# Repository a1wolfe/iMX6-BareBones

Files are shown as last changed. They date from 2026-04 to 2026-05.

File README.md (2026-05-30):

# iMX6 Bare Bones

An open source development board using the NXP i.MX 6ULL application processor. This design was completed using KiCad version 9.0.6.

See the Wiki page for updates on the status of this project.

## Related Repositories
Yocto project and images: https://github.com/a1wolfe/iMX6-BareBones-Yocto

Enclosure: https://github.com/a1wolfe/iMX6-BareBones-Enclosure

## Objectives

The iMX6 Bare Bones project was created with the following objectives:
- Create an open source PCBA for learning digital hardware and embedded linux design
- Implement minimum peripherals and interfaces to prioritize simplicity
- Specified impedance control using a standard PCB stackup published by a low-cost fabricator
- Power management using buck converters and LDOs, with no complex PMICs
- Expose interfaces such as GPIO, SPI, I2C and CAN over standard 0.1 inch / 2.54 mm headers. Users can create their own daughter PCBAs.
- Can be powered from a widely available power adapter (USB C, 15W selected)

## Architecture

System Block Diagram:

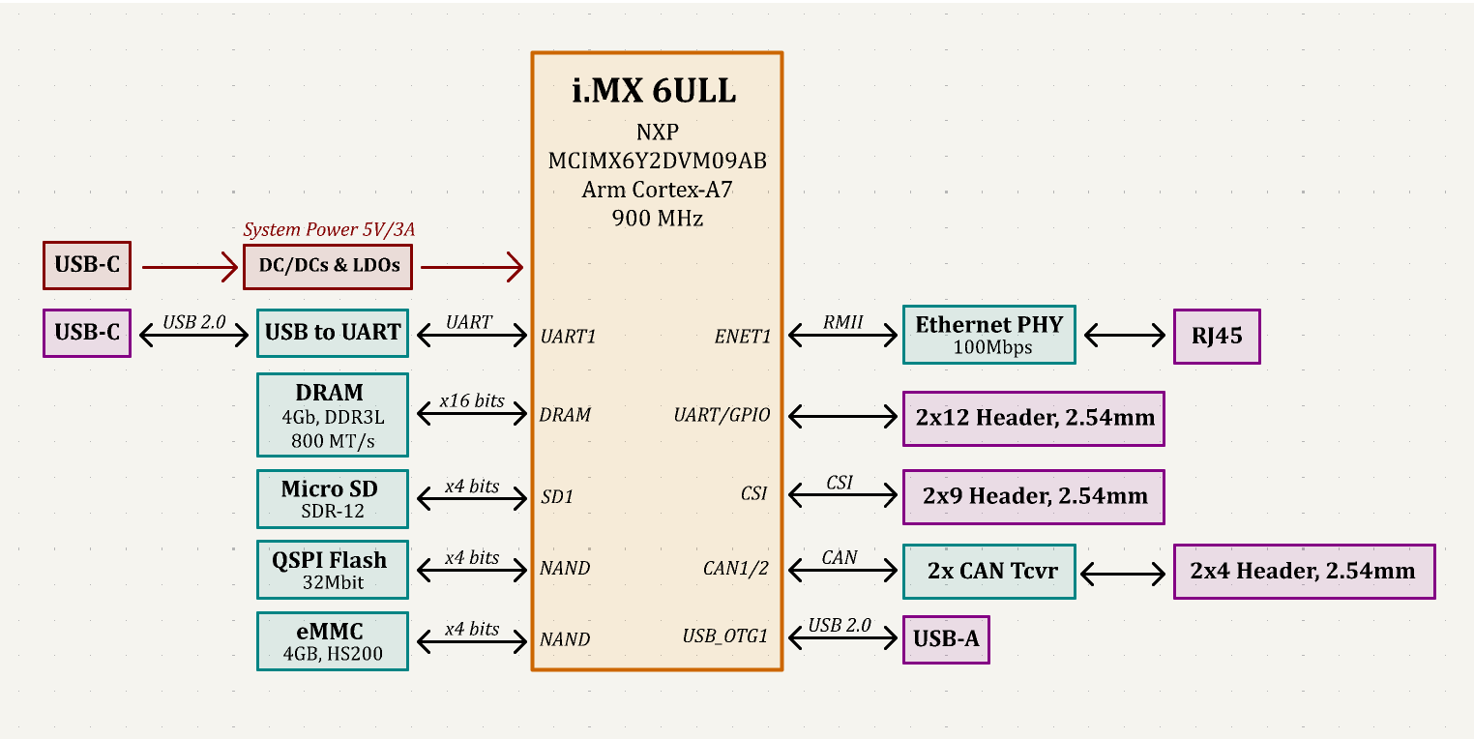
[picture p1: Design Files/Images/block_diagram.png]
block_diagram


<br>The i.MX 6ULL processor was selected mainly for it's simple and forgiving boot sequence requirements.

## PCB Design and Layout

PCBA, Top 3D View

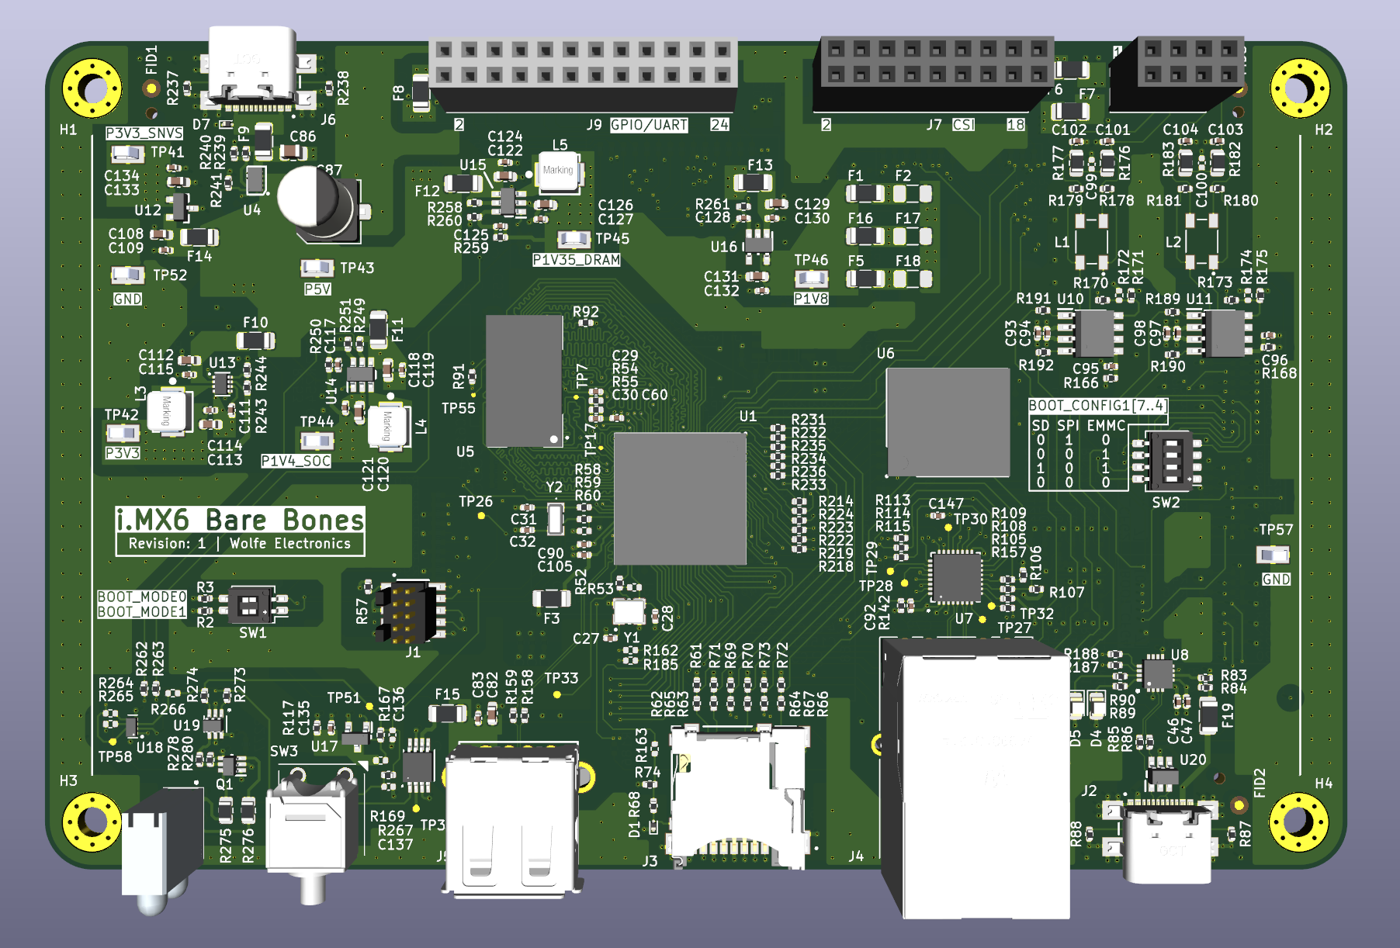
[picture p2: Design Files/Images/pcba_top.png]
pcba_top


<br>PCBA, Bottom 3D View

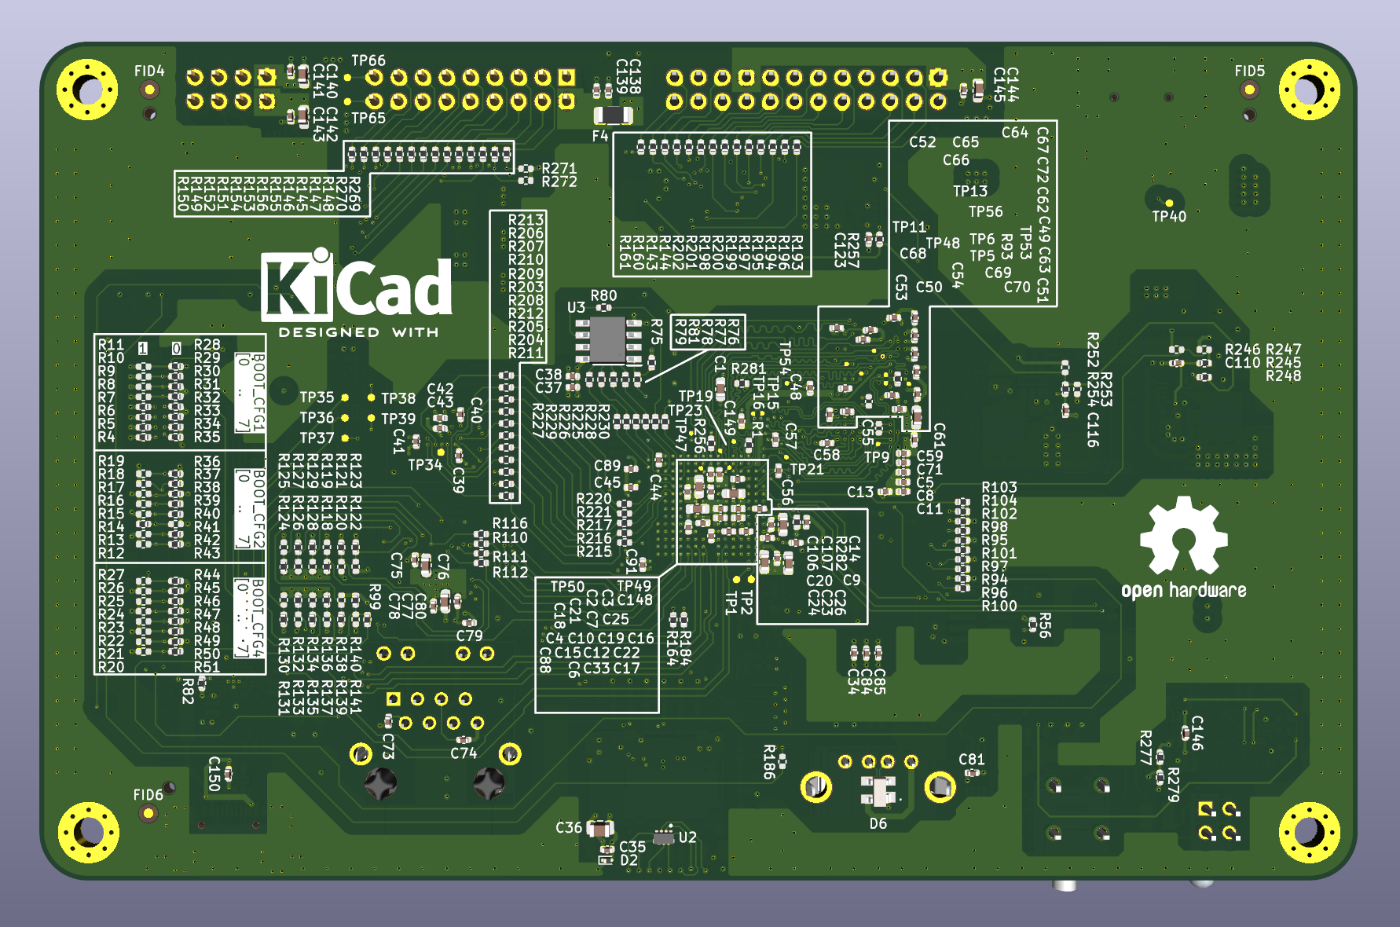
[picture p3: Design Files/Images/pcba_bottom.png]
pcba_bottom
<br>

### Placement
- All I/O connectors are placed along a single board edge. This enables easy cable insertion from the front of a system with an enclosure design.
- The power input is a USB C connector on the opposite board edge. A 15W wall adapter can be plugged into the back of a system.
- The 0.1 inch vertical headers allow daughter boards to be installed on top of the system. 
- Most components are placed on the top side of the PCB. The bottom was reserved mostly for passives and smaller SMD components. The largest component on the bottom is the QSPI flash U3, with a height of 63 mils / 1.6 mm.

### Stackup
- The PCB thickness was selected to be 1.6 mm. The design intent was to use a standard stackup listed online from a low-cost PCBA manufacturer.
- The selection was made while considering several factors to enable impedance control and DDR routing:
  - DDR3 requires 50 ohm impedance for single ended, and 100 ohm impedance for differential signals
  - Routing a x16 DDR interface while maintaining sufficient clearance between traces requires relatively thin traces. The i.MX 6ULL HDG recommends a trace width of 4.5 mils, which is used on their SODIMM reference design.
  - The thinnest outer-layer prepreg I coud find in a 1.6 mm stackup was JLC061611_3313D from JLCPCB. The prepreg thickness is 3.62 mils / 0.092 mm in this stackup.
  - Using JLC PCB's online [impdedance calculator](https://jlcpcb.com/impedance), this requires a trace width of 5.62 mm for 50 ohm single ended signals.

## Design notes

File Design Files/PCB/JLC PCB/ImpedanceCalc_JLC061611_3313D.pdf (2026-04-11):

# JLCPCB Impedance Calculator

The JLCPCB Impedance Calculator computes track width values and recommended stack-ups from user-input values of board layer, thickness, copper weight, target impedance, trace spacing (for edge-coupled pairs), and impedance trace to copper gap (coplanar waveguides). Click here (https://jlcpcb.com/help/article/User-Guide-to-the-JLCPCB-Impedance-Calculator) to see the user guide of our impedance calculator.

* The first stack-up calculated below is highly recommended as it has lowest cost and quickest turn-around.

## Impedance Configure

New Impedance | Duplicate Impedance | Calculate
24-hour PCB production. Fast Delivery to United States. | Coupons (https://jlcpcb.com/coupon-center) | APP Download (https://jlcpcb.com/download) | USD
Layers | 6 |
PCB Thickness | 1.6 |
Inner Copper Weight | 1oz |
Outer Copper Weight | 1oz |
Unit | mil |
Impedance (Ω) | Type | Signal Layer | Top Ref | Bottom Ref

Trace Spacing
（mil）

Impedance trace to
copper（mil）
(https://jlcpcb.com/) | (https://cart.jlcpcb.com/shopcart/cart) | Order Now (https://cart.jlcpcb.com/quote?spm=jlcpcb.Public.2006) | My Account

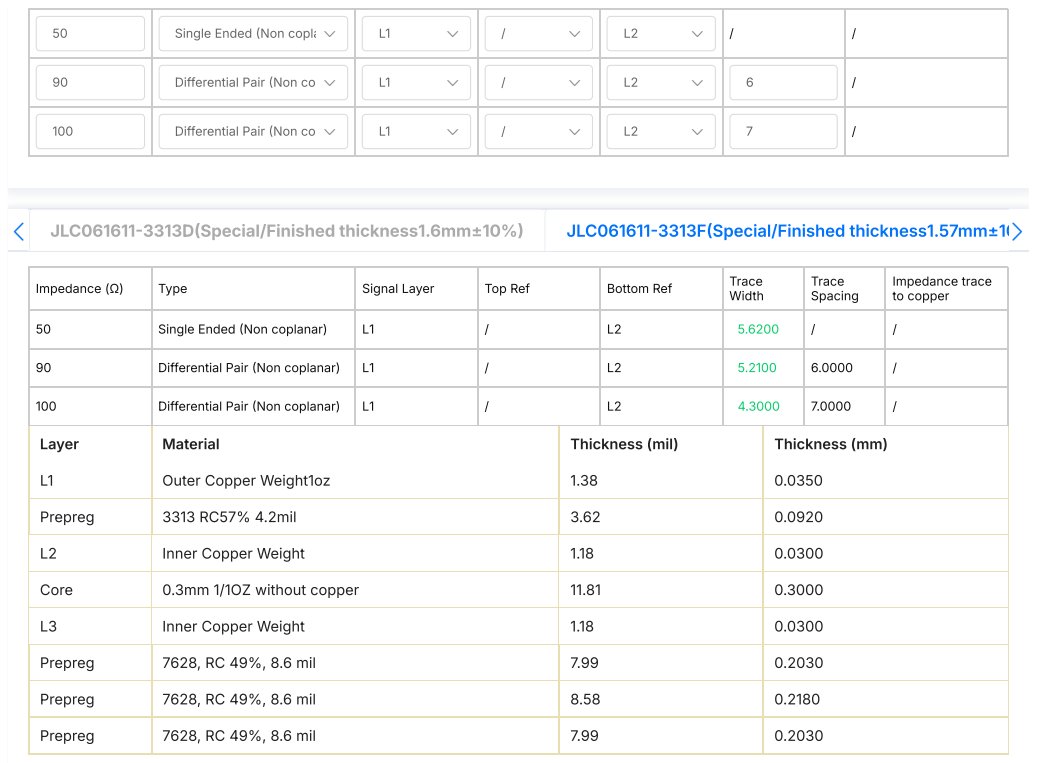
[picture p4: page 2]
JLC061611-3313D(Special/Finished thickness1.6mm±10%); JLC061611-3313F(Special/Finished thickness1.57mm±10

50 | Single Ended (Non copla | L1 | / | L2 | / | /

90 | Differential Pair (Non co | L1 | / | L2 | 6 | /

100 | Differential Pair (Non co | L1 | / | L2 | 7 | /

Impedance (Ω) | Type | Signal Layer | Top Ref | Bottom Ref | Trace Width | Trace Spacing | Impedance trace to copper

50 | Single Ended (Non coplanar) | L1 | / | L2 | 5.6200 | / | /

90 | Differential Pair (Non coplanar) | L1 | / | L2 | 5.2100 | 6.0000 | /

100 | Differential Pair (Non coplanar) | L1 | / | L2 | 4.3000 | 7.0000 | /

Layer | Material | Thickness (mil) | Thickness (mm)

L1 | Outer Copper Weight1oz | 1.38 | 0.0350

Prepreg | 3313 RC57% 4.2mil | 3.62 | 0.0920

L2 | Inner Copper Weight | 1.18 | 0.0300

Core | 0.3mm 1/1OZ without copper | 11.81 | 0.3000

L3 | Inner Copper Weight | 1.18 | 0.0300

Prepreg | 7628, RC 49%, 8.6 mil | 7.99 | 0.2030

Prepreg | 7628, RC 49%, 8.6 mil | 8.58 | 0.2180

© 2026 JLCPCB.COM All Rights Reserved. | Privacy Policy (https://jlcpcb.com/help/article/Privacy-Policy) | Terms & Conditions (https://jlcpcb.com/help/article/Terms-%26-Conditions) | Cookies Policy (https://jlcpcb.com/help/article/JLCPCB-Cookie-Notice)

L4

Core | 0.3mm 1/1OZ without copper | 11.81 | 0.3000
L5 | Inner Copper Weight | 1.18 | 0.0300
Prepreg | 3313 RC57% 4.2mil | 3.62 | 0.0920
L6 | Outer Copper Weight1oz | 1.38 | 0.0350

Inner Copper Weight
1.18

0.0300

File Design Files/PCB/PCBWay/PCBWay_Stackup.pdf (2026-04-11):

Thickness: 1.6MM | Finished Outer Copper: 1OZ | Inner Copper: 1OZ | Inner layer Residual copper ratio: 70%
Layer | Material | Thickness
| | | (mm) Thickness after lamination(mm)
| | L1-CU | Outer Base Copper
0.5OZ | 0.0175 | 0.0175
| | | (Plating to 1OZ)
| | PP | 2116 RC58%
DK:4.45 | 0.1300 | 0.1195
L2-CU | Inner Copper 1OZ | 0.0350
| | | 0.5
(Core with Cu) CORE | Core
DK:4.6 | 0.4300
L3-CU | Inner Copper 1OZ | 0.0350
PP | 7628 RC46%
DK:4.74 | 0.1960 | 0.1750
L4-CU | Inner Copper 1OZ | 0.0350

0.5

(Core with Cu) CORE | Core
DK:4.6 | 0.4300
L5-CU | Inner Copper 1OZ | 0.0350
PP | 2116 RC58%
DK:4.45 | 0.1300 | 0.1195
L6-CU | Outer Base Copper
0.5OZ | 0.0175 | 0.0175
(Plating to 1OZ)

L2-CU

L4-CU

L1-CU

PP

## CORE

L3-CU

PP

## CORE

L5-CU

PP

L6-CU

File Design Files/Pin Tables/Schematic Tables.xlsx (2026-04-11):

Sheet: BOOT_MODE
BOOT_MODE[1:0] | Boot Type
00 | Boot from fuses
01 | Serial downloader
10 | Internal boot
11 | Reserved

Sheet: BOOT_CFG
Boot Device | BOOT_CFG1[7] | BOOT_CFG1[6] | BOOT_CFG1[5] | BOOT_CFG1[4] | BOOT_CFG1[3] | BOOT_CFG1[2] | BOOT_CFG1[1] | BOOT_CFG1[0]
SD/eSD | 0 | 1 | 0 | Fast boot 0: Regular 1: Fast Boot | SD/SDXC speed 00: Normal/SDR12 01: High/SDR25 10: SDR50 11: SDR104 |  | SD power cycle enable 0: No 1: Enabled | SD loopback clock source 0: Through SD pad 1: Direct
QSPI | 0 | 0 | 0 | 1 | 0: QSPI0 | DDRSMP 000: Default 001: 111
MMC/eMMC | 0 | 1 | 1 | Fast boot 0: Regular 1: Fast Boot | SD/MMC Speed 0: Normal 1: High | Fast boot acknowledge 0: Boot ack enabled 1: Boot ack disabled | SD power cycle enable 0: No 1: Enabled | SD loopback clock source 0: Through SD pad 1: Direct
Default (SD) | 0 (SW2) | 1 (SW2) | 0 (SW2) | 0 (SW2) | 0 | 0 | 0 | 0
Boot Device | BOOT_CFG2[7] | BOOT_CFG2[6] | BOOT_CFG2[5] | BOOT_CFG2[4] | BOOT_CFG2[3] | BOOT_CFG2[2] | BOOT_CFG2[1] | BOOT_CFG2[0]
SD/eSD | SD Calibration Step 00: 1 delay cell |  | Bus Width 0: 1-bit 1: 4-bit | Port Select 00: eSDHC1 01: eSDHC2 10: Reserved 11: Reserved |  | Boot Frequencies (ARM/DDR) 0: 500 / 400 MHz 1: 250 / 200 MHz | SD VOLTAGE SELECTION 0: 3.3V 1: 1.8V | Reserved
QSPI | Reserved | HSPHS (Half Speed Phase Selection) 0: select sampling at non-inverted clock 1: select sampling at inverted clock | HSDLY (Half Speed Delay selection) 0: one clock delay 1: two clock delay | FSPHS (Full Speed Phase Selection) 0: select sampling at non-inverted clock 1: select sampling at inverted clock | FSDLY (Full Speed Delay selection) 0: one clock delay 1: two clock delay | Boot Frequencies (ARM/DDR) 0: 500 / 400 MHz 1: 250 / 200 MHz | Reserved | Reserved
MMC/eMMC | Bus Width 000: 1-bit 001: 4-bit 010: 8-bit 101: 4-bit DDR (MMC 4.4) 110: 8-bit DDR (MMC 4.4) Else: Reserved |  |  | Port Select 00: eSDHC1 01: eSDHC2 10: Reserved 11: Reserved |  | Boot Frequencies (ARM/DDR) 0: 500 / 400 MHz 1: 250 / 200 MHz | SD VOLTAGE SELECTION 0: 3.3V 1: 1.8V | Reserved
Default (SD) | 0 | 0 | 1 | 0 | 0 | 0 | 0 | 0
Boot Device | BOOT_CFG4[7] | BOOT_CFG4[6] | BOOT_CFG4[5] | BOOT_CFG4[4] | BOOT_CFG4[3] | BOOT_CFG4[2] | BOOT_CFG4[1] | BOOT_CFG4[0]
SD/eSD MMC/eMMC | Reserved | EEPROM Recovery Enable 0: Disabled 1: Enabled Fuse is Reserved for 'Serial-ROM' Boot mode | eCSPI chip select 00: ECSPIx_SS0 (default) 01: ECSPIx_SS1 10: ECSPIx_SS2 11: ECSPIx_SS3 |  | eCSPI Addressing 0: 2-bytes (16-bit) 1: 3-bytes (24-bit) | Port Select 000: eCSPI1 001: eCSPI2 010: eCSPI3 011: eCSPI4 100 to 111: Reserved
Default (SD) | 0 | 0 | 0 | 0 | 0 | 0 | 0 | 0

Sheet: RMII
Pin Name | Description | Pin Name | Description
PHY_ADDRESS[2:0] | PHY Address (00XXX) Default: 00001 | CONFIG[2:0] | Interface Mode Default: 001 (RMII)
 |  |  |  | Pin Name | Description
 |  |  |  | ISO | Isolate Mode Pull-up: Enable Pull-down (default): Disable
 |  |  |  | SPEED | Speed mode Pull-up (default) = 100 Mbps Pull-down = 10 Mbps
 |  |  |  | DUPLEX | Duplex mode Pull-up (default) = Half-duplex Pull-down = Full-duplex
 |  |  |  | NWAYEN | Nway auto-negotiation enable Pull-up (default) = Enable auto-negotiation Pull-down = Disable auto-negotiation
 |  |  |  | B-CAST_OFF | Broadcast off – for PHY Address 0 Pull-up = PHY Address 0 is set as an unique PHY address Pull-down (default) = PHY Address 0 is set as a broadcast PHY address
 |  |  |  | NAND_Tree# | NAND tree mode Pull-up (default) = Disable Pull-down = Enable

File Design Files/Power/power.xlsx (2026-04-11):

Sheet: Power Budget
Device | Pins | Voltage | Rail | Continuous Max (mA) | N (IO pins) | C (cap load, pF) | Freq (Hz) | Sequence
iMX6 | VDD_SOC_IN | 1.4 | P1V4_SOC | 500 | N/A | N/A | N/A | 3
iMX6 | VDD_HIGH_IN | 3.3 | P3V3 | 125 | N/A | N/A | N/A | 2
iMX6 | VDD_SNVS_IN | 3.3 | P3V3_STBY | 0.5 | N/A | N/A | N/A | 1
iMX6 | NVCC_DRAM | 1.35 | P1V35_DRAM | 50 | N/A | N/A | N/A
iMX6 | VDDA_ADC_3P3 | 3.3 | P3V3 | 35 | N/A | N/A | N/A
iMX6 | USB_OTG1_VBUS | 5 | P5V | 50 | N/A | N/A | N/A
iMX6 | USB_OTG2_VBUS | 5 | P5V | 50 | N/A | N/A | N/A
iMX6 | NVCC_SD1 | 3.3 | P3V3 | 9.90 | 6 | 10 | 50000000
iMX6 | NVCC_NAND | 1.8 | P1V8 | 6.12 | 17 | 10 | 20000000
iMX6 | NVCC_CSI | 1.8 | P1V8 | 2.59 | 12 | 10 | 12000000
iMX6 | NVCC_LCD | 3.3 | P3V3 | 28.71 | 29 | 10 | 30000000
iMX6 | NVCC_ENET | 3.3 | P3V3 | 13.20 | 16 | 10 | 25000000
iMX6 | NVCC_UART | 3.3 | P3V3 | 0.06 | 16 | 10 | 115200
iMX6 | NVCC_GPIO | 3.3 | P3V3 | 0.0033 | 10 | 10 | 10000
iMX6 | DRAM_VREF | 1.35 | P1V35_DRAM | 1 | N/A | N/A | N/A
MT41K256M16TW-107 | VDD/VDDQ | 1.35 | P1V35_DRAM | 320
CP2102N | VREGIN/VDD | 3.3 | P3V3 | 9.5
eMMC | VCCQ | 1.8 | P1V8 | 185
uSD | VDD | 3.3 | P3V3 | 300
QSPI Flash | VCC | 3.3 | P3V3 | 17
KSZ8081 phy | VDDA/VDDIO | 3.3 | P3V3 | 47
CAN transceiver (x2) | VCC | 5 | P5V | 140
CAN transceiver (x2) | VIO | 3.3 | P3V3 | 0.7

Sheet: P5V OVLO
 | min | typical | max
Vth(ovlo) | 1.164 | 1.227 | 1.287 | Vovlo desired | 8 | From NX20P5090 datasheet:
R1 | 990000 | 1000000 | 1010000 | R2 calculated | 181160.4902
R2 | 180180 | 182000 | 183820 | R2 actual | 182000
Vovlo | 7.559604396 | 7.968758242 | 8.358428571

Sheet: P3V3
From MPS2182 Datasheet:
 |  |  | Vout | 3.3
 |  |  | Vin | 5
 |  |  | Max I (A) | 0.78
 |  |  | delta I | 0.234
 |  |  | fosc | 1200000
 |  |  | L | 3.995726496e-06
 |  |  | Calculated value outside of recommended range, will select 1uH.
 |  |  |  |  | Vout | 3.3
 |  |  |  |  | Vin | 5
 |  |  |  |  | fsw | 1200000
 |  | Selected X7R, 10uF input cap |  |  | C2 | 2.2e-05
 |  |  |  |  | L1 | 1e-06
 |  |  |  |  | delta Vout | 0.004427083333
 |  |  |  |  | Select 22uF for output capacitor
For 3.3V, selected 200k and 44.2k
Vout | 3.3
R2 | 44444.44444
R1 | 200000
R2 select | 44200
Vout actual | 3.314932127

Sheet: P1V4_SOC & P1V35_DRAM
P1V4_SOC |  | P1V35_DRAM
R1 | 100000 | R1 | 100000
R2 | 75000 | R2 | 80000
Vout | 1.4 | Vout | 1.35

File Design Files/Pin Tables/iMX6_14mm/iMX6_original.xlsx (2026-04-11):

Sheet: iMX6_Original
Count | Pin | Net | Electrical | Shape | Alignment | Coordinate 1 | Coordinate 2 | Symbol
1 | A1 | VSS_1 | Passive | Line | Right | 0 mils | 0 mils | GND
1 | C4 | NVCC_SD1 | Passive | Line | Right | 0 | 400 | SD
1 | E7 | NVCC_NAND | Passive | Line | Right | 0 | 400 | NAND
1 | B4 | NAND_ALE | Passive | Line | Left | 2300 | 400 | NAND
1 | C8 | NAND_WE_B | Passive | Line | Left | 2300 | 500 | NAND
1 | D8 | NAND_RE_B | Passive | Line | Left | 2300 | 600 | NAND
1 | D7 | NAND_DATA00 | Passive | Line | Left | 2300 | 700 | NAND
1 | A8 | LCD_CLK | Passive | Line | Left | 2300 | 400 | LCD
1 | B9 | LCD_DATA00 | Passive | Line | Left | 2300 | 600 | LCD
1 | A9 | LCD_DATA01 | Passive | Line | Left | 2300 | 700 | LCD
1 | E10 | LCD_DATA02 | Passive | Line | Left | 2300 | 800 | LCD
1 | D10 | LCD_DATA03 | Passive | Line | Left | 2300 | 900 | LCD
1 | C10 | LCD_DATA04 | Passive | Line | Left | 2300 | 1000 | LCD
1 | B10 | LCD_DATA05 | Passive | Line | Left | 2300 | 1100 | LCD
1 | F16 | ENET1_RX_DATA0 | Passive | Line | Right | 0 mils | 600 | ENET
1 | E17 | ENET1_RX_DATA1 | Passive | Line | Right | 0 mils | 700 | ENET
1 | A17 | VSS_2 | Passive | Line | Right | 0 mils | 1600 mils | GND
1 | C1 | SD1_CLK | Passive | Line | Left | 2300 | 400 | SD
1 | C2 | SD1_CMD | Passive | Line | Left | 2300 | 500 | SD
1 | B3 | SD1_DATA0 | Passive | Line | Left | 2300 | 700 | SD
1 | B7 | NAND_DATA01 | Passive | Line | Left | 2300 | 800 | NAND
1 | A7 | NAND_DATA02 | Passive | Line | Left | 2300 | 900 | NAND
1 | D6 | NAND_DATA03 | Passive | Line | Left | 2300 | 1000 | NAND
1 | C6 | NAND_DATA04 | Passive | Line | Left | 2300 | 1100 | NAND
1 | A10 | LCD_DATA06 | Passive | Line | Left | 2300 | 1200 | LCD
1 | D11 | LCD_DATA07 | Passive | Line | Left | 2300 | 1300 | LCD
1 | B11 | LCD_DATA08 | Passive | Line | Left | 2300 | 1400 | LCD
1 | A11 | LCD_DATA09 | Passive | Line | Left | 2300 | 1500 | LCD
1 | E12 | LCD_DATA10 | Passive | Line | Left | 2300 | 1600 | LCD
1 | D12 | LCD_DATA11 | Passive | Line | Left | 2300 | 1700 | LCD
1 | C12 | LCD_DATA12 | Passive | Line | Left | 2300 | 1800 | LCD
1 | E16 | ENET1_RX_EN | Passive | Line | Right | 0 mils | 900 | ENET
1 | B12 | LCD_DATA13 | Passive | Line | Left | 2300 | 1900 | LCD
1 | D15 | ENET1_RX_ER | Passive | Line | Right | 0 mils | 1000 | ENET
1 | B2 | SD1_DATA1 | Passive | Line | Left | 2300 | 800 | SD
1 | B1 | SD1_DATA2 | Passive | Line | Left | 2300 | 900 | SD
1 | C3 | VSS_3 | Passive | Line | Right | 0 mils | 3600 mils | GND
1 | A2 | SD1_DATA3 | Passive | Line | Left | 2300 | 1000 | SD
1 | B6 | NAND_DATA05 | Passive | Line | Left | 2300 | 1200 | NAND
1 | A6 | NAND_DATA06 | Passive | Line | Left | 2300 | 1300 | NAND
1 | C7 | VSS_4 | Passive | Line | Right | 0 mils | 4000 mils | GND
1 | A5 | NAND_DATA07 | Passive | Line | Left | 2300 | 1400 | NAND
1 | A12 | LCD_DATA14 | Passive | Line | Left | 2300 | 2000 | LCD
1 | D13 | LCD_DATA15 | Passive | Line | Left | 2300 | 2100 | LCD
1 | C11 | VSS_5 | Passive | Line | Right | 0 mils | 4400 mils | GND
1 | C13 | LCD_DATA16 | Passive | Line | Left | 2300 | 2200 | LCD
1 | B13 | LCD_DATA17 | Passive | Line | Left | 2300 | 2300 | LCD
1 | A13 | LCD_DATA18 | Passive | Line | Left | 2300 | 2400 | LCD
1 | C15 | VSS_6 | Passive | Line | Right | 0 mils | 4800 mils | GND
1 | F14 | ENET1_TX_CLK | Passive | Line | Left | 2300 | 400 | ENET
1 | E15 | ENET1_TX_DATA0 | Passive | Line | Left | 2300 | 600 | ENET
1 | F4 | NVCC_CSI | Passive | Line | Right | 0 | 700 | CSI
1 | F5 | CSI_MCLK | Passive | Line | Left | 2300 | 900 | CSI
1 | E5 | CSI_PIXCLK | Passive | Line | Left | 2300 | 1000 | CSI
1 | F2 | CSI_VSYNC | Passive | Line | Left | 2300 | 600 | CSI
1 | C5 | NAND_CE0_B | Passive | Line | Left | 2300 | 1600 | NAND
1 | B5 | NAND_CE1_B | Passive | Line | Left | 2300 | 1700 | NAND
1 | A4 | NAND_CLE | Passive | Line | Left | 2300 | 1800 | NAND
1 | D5 | NAND_WP_B | Passive | Line | Left | 2300 | 1900 | NAND
1 | D14 | LCD_DATA19 | Passive | Line | Left | 2300 | 2500 | LCD
1 | C14 | LCD_DATA20 | Passive | Line | Left | 2300 | 2600 | LCD
1 | B14 | LCD_DATA21 | Passive | Line | Left | 2300 | 2700 | LCD
1 | A14 | LCD_DATA22 | Passive | Line | Left | 2300 | 2800 | LCD
1 | B16 | LCD_DATA23 | Passive | Line | Left | 2300 | 2900 | LCD
1 | B8 | LCD_ENABLE | Passive | Line | Left | 2300 | 3100 | LCD
1 | E14 | ENET1_TX_DATA1 | Passive | Line | Left | 2300 | 700 | ENET
1 | F15 | ENET1_TX_EN | Passive | Line | Left | 2300 | 900 | ENET
1 | C17 | ENET2_RX_DATA0 | Passive | Line | Right | 0 mils | 1200 | ENET
1 | F3 | CSI_HSYNC | Passive | Line | Left | 2300 | 700 | CSI
1 | E4 | CSI_DATA00 | Passive | Line | Left | 2300 | 800 | CSI
1 | E3 | CSI_DATA01 | Passive | Line | Left | 2300 | 900 | CSI
1 | E2 | CSI_DATA02 | Passive | Line | Left | 2300 | 1000 | CSI
1 | E1 | CSI_DATA03 | Passive | Line | Left | 2300 | 1100 | CSI
1 | A3 | NAND_READY_B | Passive | Line | Left | 2300 | 2000 | NAND
1 | E6 | NAND_DQS | Passive | Line | Left | 2300 | 2100 | NAND
1 | E8 | VSS_7 | Passive | Line | Right | 0 mils | 7500 mils | GND
1 | D9 | LCD_HSYNC | Passive | Line | Left | 2300 | 3200 | LCD
1 | E9 | LCD_RESET | Passive | Line | Left | 2300 | 3300 | LCD
1 | E11 | VSS_8 | Passive | Line | Right | 0 mils | 7800 mils | GND
1 | C9 | LCD_VSYNC | Passive | Line | Left | 2300 | 3400 | LCD
1 | E13 | NVCC_LCD | Passive | Line | Right | 0 | 400 | LCD
1 | C16 | ENET2_RX_DATA1 | Passive | Line | Right | 0 mils | 1300 | ENET
1 | B17 | ENET2_RX_EN | Passive | Line | Right | 0 mils | 1500 | ENET
1 | D16 | ENET2_RX_ER | Passive | Line | Right | 0 mils | 1600 | ENET
1 | D17 | ENET2_TX_CLK | Passive | Line | Left | 2300 | 1100 | ENET
1 | N1 | DRAM_ODT0 | Passive | Line | Left | 2300 mils | 3100 | DRAM | B
1 | D4 | CSI_DATA04 | Passive | Line | Left | 2300 | 1200 | CSI
1 | D3 | CSI_DATA05 | Passive | Line | Left | 2300 | 1300 | CSI
1 | D2 | CSI_DATA06 | Passive | Line | Left | 2300 | 1400 | CSI
1 | D1 | CSI_DATA07 | Passive | Line | Left | 2300 | 1500 | CSI
1 | F6 | VSS_9 | Passive | Line | Right | 0 mils | 9000 mils | GND
1 | F7 | VSS_10 | Passive | Line | Right | 0 mils | 9100 mils | GND
1 | F8 | VSS_11 | Passive | Line | Right | 0 mils | 9200 mils | GND
1 | F9 | VSS_12 | Passive | Line | Right | 0 mils | 9300 mils | GND
1 | F10 | VSS_13 | Passive | Line | Right | 0 mils | 9400 mils | GND
1 | F11 | VSS_14 | Passive | Line | Right | 0 mils | 9500 mils | GND
1 | F12 | VSS_15 | Passive | Line | Right | 0 mils | 9600 mils | GND
1 | A15 | ENET2_TX_DATA0 | Passive | Line | Left | 2300 | 1200 | ENET
1 | A16 | ENET2_TX_DATA1 | Passive | Line | Left | 2300 | 1400 | ENET
1 | B15 | ENET2_TX_EN | Passive | Line | Left | 2300 | 1500 | ENET
1 | F13 | NVCC_ENET | Passive | Line | Right | 0 mils | 300 | ENET
1 | M13 | ADC_VREFH | Passive | Line | Left | 2300 mils | 5400 mils | PMU
1 | L5 | DRAM_ADDR00 | Passive | Line | Right | 0 mils | 0 mils | DRAM | B
1 | H2 | DRAM_ADDR01 | Passive | Line | Right | 0 mils | 100 mils | DRAM | B
1 | G3 | VSS_16 | Passive | Line | Right | 0 mils | 10400 mils | GND
1 | G4 | DRAM_RESET | Passive | Line | Right | 0 mils | 3400 | DRAM | B
1 | G5 | VSS_17 | Passive | Line | Right | 0 mils | 10600 mils | GND
1 | G6 | NVCC_DRAM_1 | Passive | Line | Right | 0 mils | 700 mils | PMU
1 | G7 | VSS_18 | Passive | Line | Right | 0 mils | 10800 mils | GND
1 | G8 | VDD_SOC_CAP_1 | Passive | Line | Left | 2100 mils | 700 mils | PMU
1 | G9 | VDD_ARM_CAP_1 | Passive | Line | Left | 2100 mils | 0 mils | PMU
1 | G10 | VDD_ARM_CAP_2 | Passive | Line | Left | 2100 mils | 100 mils | PMU
1 | G11 | VDD_ARM_CAP_3 | Passive | Line | Left | 2100 mils | 200 mils | PMU
1 | G12 | VSS_19 | Passive | Line | Right | 0 mils | 11300 mils | GND
1 | T10 | BOOT_MODE0 | Passive | Line | Left | 2300 mils | 300 | CTRL
1 | U10 | BOOT_MODE1 | Passive | Line | Left | 2300 mils | 400 | CTRL
1 | G15 | VSS_20 | Passive | Line | Right | 0 mils | 11600 mils | GND
1 | P16 | CCM_CLK1_N | Passive | Line | Left | 2300 mils | 500 | CTRL
1 | P17 | CCM_CLK1_P | Passive | Line | Left | 2300 mils | 600 | CTRL
1 | M1 | DRAM_SDBA0 | Passive | Line | Right | 0 mils | 1200 mils | DRAM | B
1 | K1 | DRAM_ADDR02 | Passive | Line | Right | 0 mils | 200 mils | DRAM | B
1 | M2 | DRAM_ADDR03 | Passive | Line | Right | 0 mils | 300 mils | DRAM | B
1 | K4 | DRAM_ADDR04 | Passive | Line | Right | 0 mils | 400 mils | DRAM | B
1 | N2 | DRAM_CS0_B | Passive | Line | Right | 0 | 2100 | DRAM | B
1 | H6 | NVCC_DRAM_2 | Passive | Line | Right | 0 mils | 800 mils | PMU
1 | H7 | VSS_21 | Passive | Line | Right | 0 mils | 12500 mils | GND
1 | H8 | VDD_SOC_CAP_2 | Passive | Line | Left | 2100 mils | 800 mils | PMU
1 | H9 | VDD_SOC_IN_1 | Passive | Line | Right | 0 mils | 0 mils | PMU
1 | H10 | VDD_SOC_IN_2 | Passive | Line | Right | 0 mils | 100 mils | PMU
1 | H11 | VDD_ARM_CAP_4 | Passive | Line | Left | 2100 mils | 300 mils | PMU
1 | H12 | VSS_22 | Passive | Line | Right | 0 mils | 13000 mils | GND
1 | U9 | CCM_PMIC_STBY_REQ | Passive | Line | Left | 2300 mils | 700 | CTRL
1 | R13 | GPANAIO | Passive | Line | Left | 2300 mils | 800 | CTRL
1 | P15 | JTAG_MOD | Passive | Line | Left | 2300 mils | 900 | CTRL
1 | M14 | JTAG_TCK | Passive | Line | Left | 2300 mils | 1000 | CTRL
1 | N16 | JTAG_TDI | Passive | Line | Left | 2300 mils | 1100 | CTRL
1 | J1 | DRAM_SDWE_B | Passive | Line | Right | 0 mils | 2600 | DRAM | B
1 | J2 | DRAM_CAS_B | Passive | Line | Right | 0 mils | 2500 | DRAM | B
1 | M3 | DRAM_SDCKE0 | Passive | Line | Left | 2300 mils | 2500 | DRAM | B
1 | L1 | DRAM_ADDR05 | Passive | Line | Right | 0 mils | 500 mils | DRAM | B
1 | J5 | VSS_23 | Passive | Line | Right | 0 mils | 14000 mils | GND
1 | J6 | NVCC_DRAM_3 | Passive | Line | Right | 0 mils | 900 mils | PMU
1 | J7 | VSS_24 | Passive | Line | Right | 0 mils | 14200 mils | GND
1 | J8 | VDD_SOC_CAP_3 | Passive | Line | Left | 2100 mils | 900 mils | PMU
1 | J9 | VDD_SOC_IN_3 | Passive | Line | Right | 0 mils | 200 mils | PMU
1 | J10 | VDD_SOC_IN_4 | Passive | Line | Right | 0 mils | 300 mils | PMU
1 | J11 | VDD_SOC_CAP_4 | Passive | Line | Left | 2100 mils | 1000 mils | PMU
1 | J12 | VSS_25 | Passive | Line | Left | 2300 mils | 200 mils | GND
1 | K13 | GPIO1_IO00 | Passive | Line | Left | 2300 mils | 300 | GPIO
1 | N15 | JTAG_TDO | Passive | Line | Left | 2300 mils | 1200 | CTRL
1 | P14 | JTAG_TMS | Passive | Line | Left | 2300 mils | 1300 | CTRL
1 | N14 | JTAG_TRST_B | Passive | Line | Left | 2300 mils | 1400 | CTRL
1 | M12 | NGND_KEL0 | Passive | Line | Left | 2300 mils | 3000 | GND
1 | G2 | DRAM_ADDR06 | Passive | Line | Right | 0 mils | 600 mils | DRAM | B
1 | H1 | DRAM_SDBA1 | Passive | Line | Right | 0 mils | 1300 mils | DRAM | B
1 | H4 | DRAM_ADDR07 | Passive | Line | Right | 0 mils | 700 mils | DRAM | B
1 | J4 | DRAM_ADDR08 | Passive | Line | Right | 0 mils | 800 mils | DRAM | B
1 | L2 | DRAM_ADDR09 | Passive | Line | Right | 0 mils | 900 mils | DRAM | B
1 | K6 | NVCC_DRAM_4 | Passive | Line | Right | 0 mils | 1000 mils | PMU
1 | K7 | VSS_26 | Passive | Line | Left | 2300 mils | 1400 mils | GND
1 | K8 | VDD_SOC_CAP_5 | Passive | Line | Left | 2100 mils | 1100 mils | PMU
1 | K9 | VDD_SOC_IN_5 | Passive | Line | Right | 0 mils | 400 mils | PMU
1 | K10 | VDD_SOC_IN_6 | Passive | Line | Right | 0 mils | 500 mils | PMU
1 | K11 | VDD_SOC_CAP_6 | Passive | Line | Left | 2100 mils | 1200 mils | PMU
1 | K12 | VSS_27 | Passive | Line | Left | 2300 mils | 1900 mils | GND
1 | L15 | GPIO1_IO01 | Passive | Line | Left | 2300 mils | 400 | GPIO
1 | H13 | NVCC_UART | Passive | Line | Right | 0 mils | 300 | UART
1 | R8 | ONOFF | Passive | Line | Left | 2300 mils | 1600 | CTRL
1 | P8 | POR_B | Passive | Line | Left | 2300 mils | 1700 | CTRL
1 | L14 | GPIO1_IO02 | Passive | Line | Left | 2300 mils | 500 | GPIO
1 | M4 | DRAM_ADDR10 | Passive | Line | Right | 0 mils | 1000 mils | DRAM | B
1 | K3 | DRAM_ADDR11 | Passive | Line | Right | 0 mils | 1100 mils | DRAM | B
1 | L3 | VSS_28 | Passive | Line | Left | 2300 mils | 2700 mils | GND
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

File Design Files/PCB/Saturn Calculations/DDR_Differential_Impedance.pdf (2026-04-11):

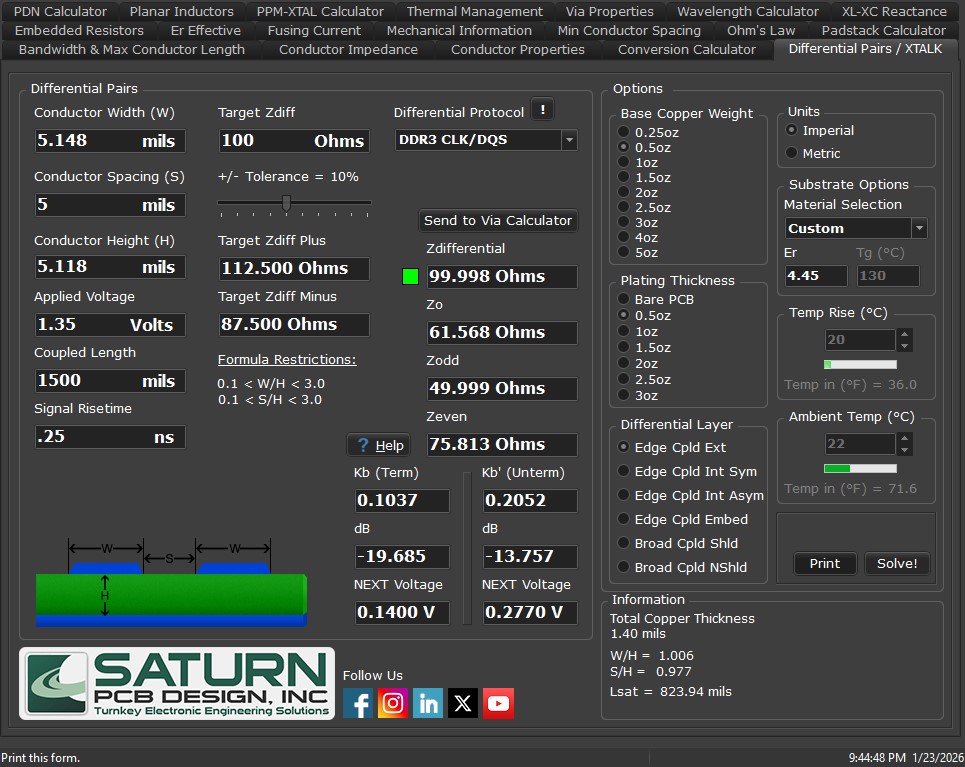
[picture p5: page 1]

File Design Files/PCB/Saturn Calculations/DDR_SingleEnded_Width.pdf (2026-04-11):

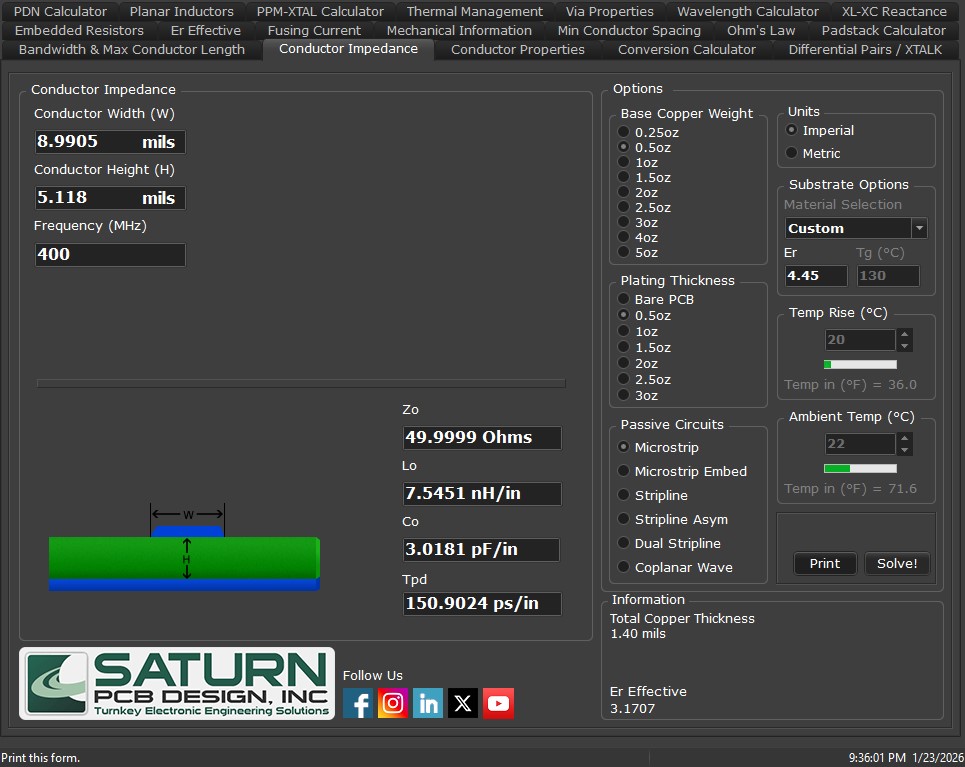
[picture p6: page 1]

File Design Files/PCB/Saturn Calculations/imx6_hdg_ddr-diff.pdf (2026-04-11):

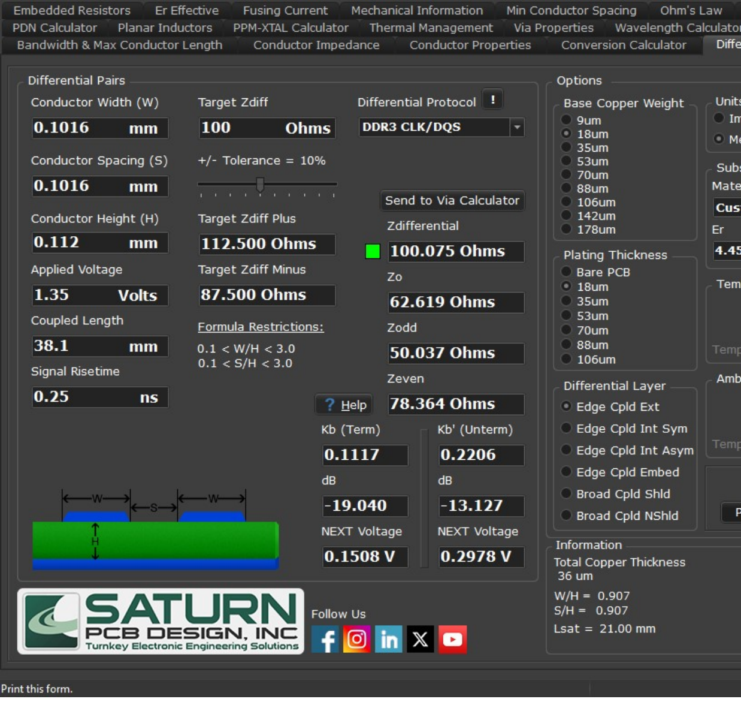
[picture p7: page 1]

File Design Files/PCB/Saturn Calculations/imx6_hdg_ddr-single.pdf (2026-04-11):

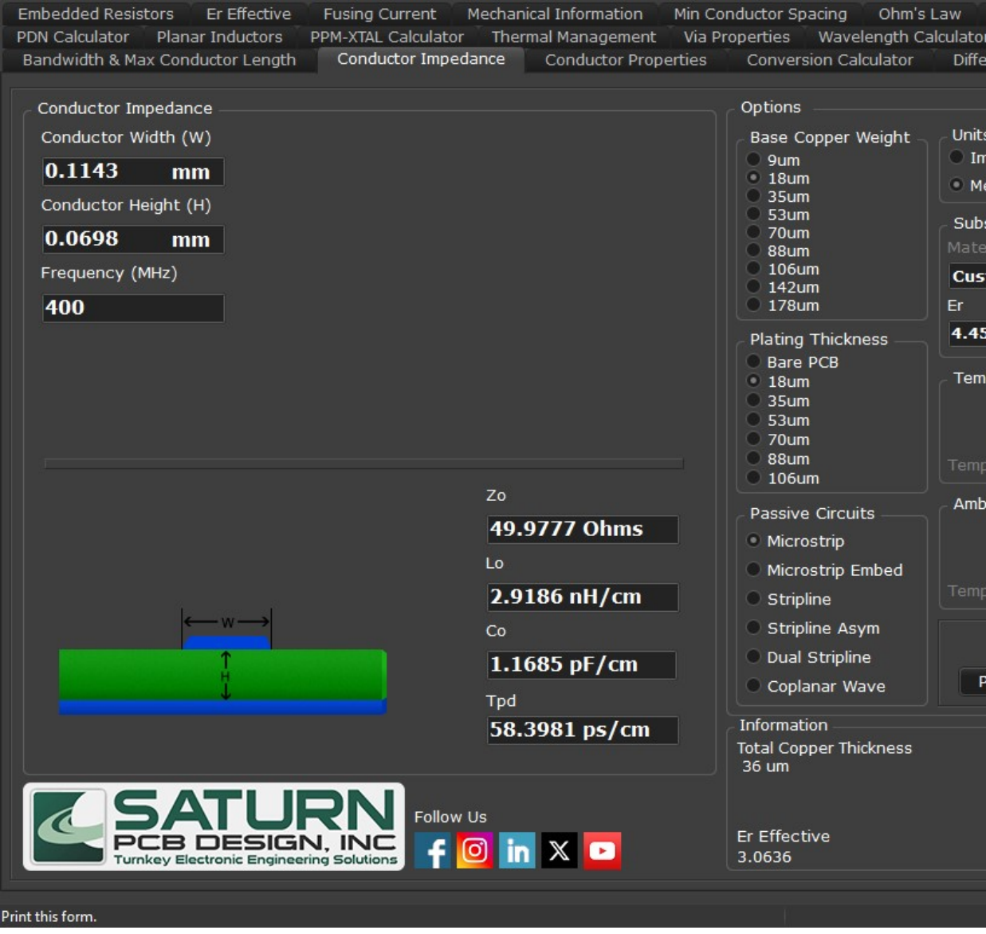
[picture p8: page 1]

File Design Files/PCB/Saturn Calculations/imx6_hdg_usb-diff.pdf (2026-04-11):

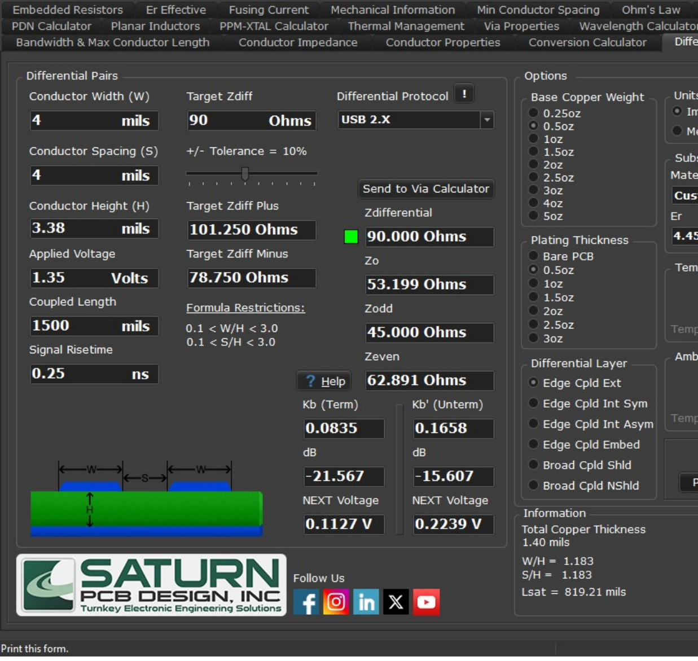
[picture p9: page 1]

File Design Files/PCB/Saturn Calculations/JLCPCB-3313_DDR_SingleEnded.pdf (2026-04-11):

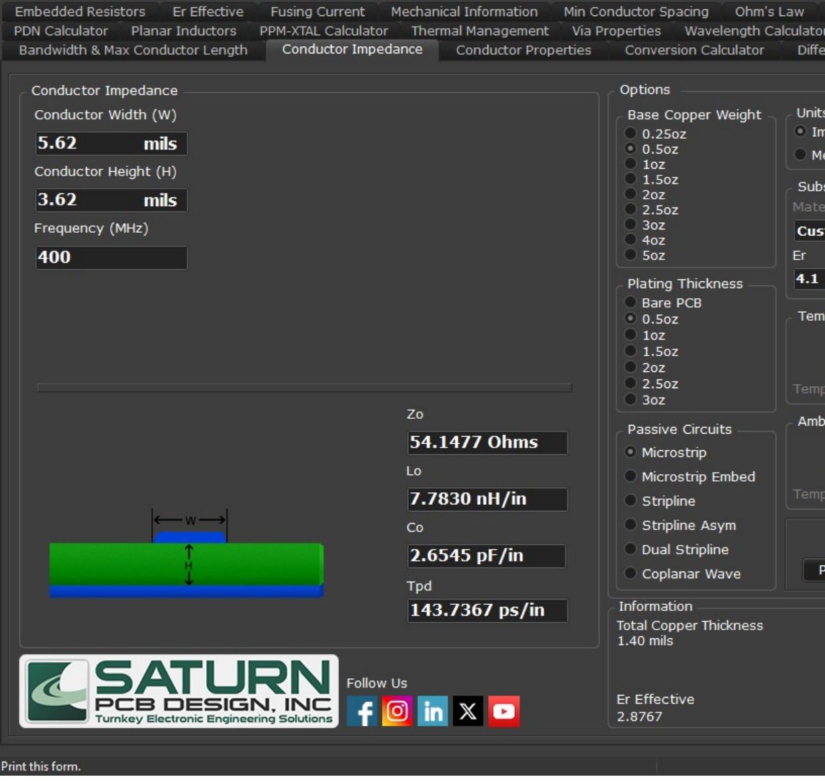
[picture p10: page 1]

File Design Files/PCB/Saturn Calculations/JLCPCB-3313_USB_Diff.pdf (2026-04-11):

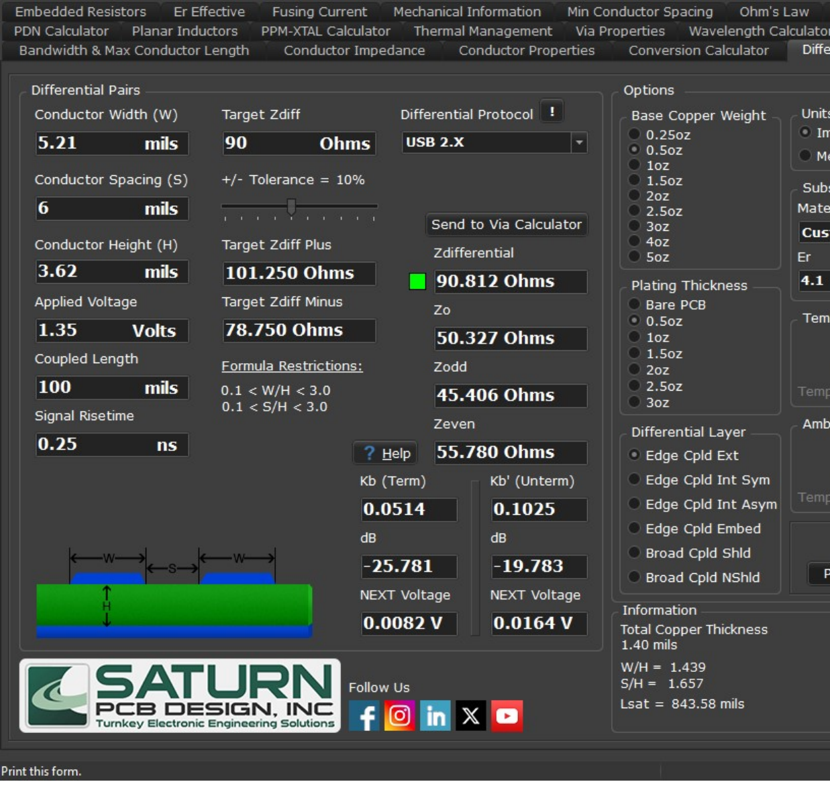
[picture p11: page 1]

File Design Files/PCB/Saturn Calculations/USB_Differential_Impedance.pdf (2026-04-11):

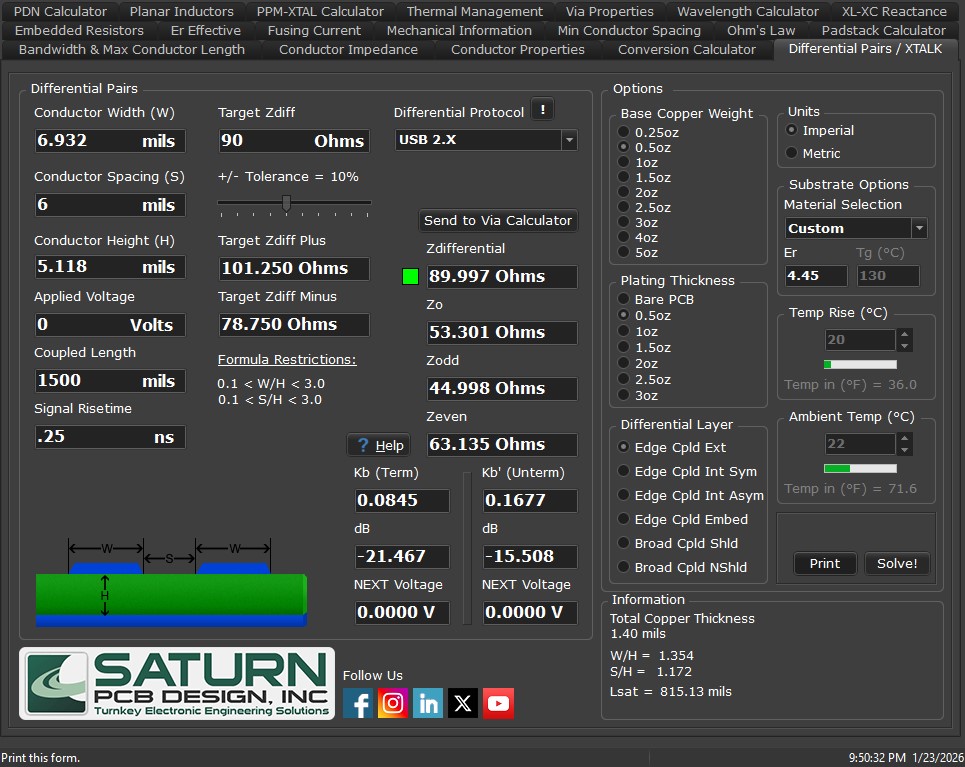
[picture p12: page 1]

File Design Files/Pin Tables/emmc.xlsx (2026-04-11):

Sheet: Sheet1
 | Pin | Name | Type | Symbol | Align | x | y
1 | A1 | NC_1 | Passive | Line | Right | 0 mils | 400
1 | A2 | NC_2 | Passive | Line | Right | 0 mils | 500
1 | A8 | NC_3 | Passive | Line | Right | 0 mils | 600
1 | A9 | NC_4 | Passive | Line | Right | 0 mils | 700
1 | A10 | NC_5 | Passive | Line | Right | 0 mils | 800
1 | A11 | NC_6 | Passive | Line | Right | 0 mils | 900
1 | A12 | NC_7 | Passive | Line | Right | 0 mils | 1000
1 | A13 | NC_8 | Passive | Line | Right | 0 mils | 1100
1 | A14 | NC_9 | Passive | Line | Right | 0 mils | 1200
1 | B1 | NC_10 | Passive | Line | Right | 0 mils | 1300
1 | B7 | NC_11 | Passive | Line | Right | 0 mils | 1400
1 | B8 | NC_12 | Passive | Line | Right | 0 mils | 1500
1 | B9 | NC_13 | Passive | Line | Right | 0 mils | 1600
1 | B10 | NC_14 | Passive | Line | Right | 0 mils | 1700
1 | B11 | NC_15 | Passive | Line | Right | 0 mils | 1800
1 | B12 | NC_16 | Passive | Line | Right | 0 mils | 1900
1 | B13 | NC_17 | Passive | Line | Right | 0 mils | 2000
1 | B14 | NC_18 | Passive | Line | Right | 0 mils | 2100
1 | C1 | NC_19 | Passive | Line | Right | 0 mils | 2200
1 | C3 | NC_20 | Passive | Line | Right | 0 mils | 2300
1 | C5 | NC_21 | Passive | Line | Right | 0 mils | 2400
1 | C7 | NC_22 | Passive | Line | Right | 0 mils | 2500
1 | C8 | NC_23 | Passive | Line | Right | 0 mils | 2600
1 | C9 | NC_24 | Passive | Line | Right | 0 mils | 2700
1 | C10 | NC_25 | Passive | Line | Right | 0 mils | 2800
1 | C11 | NC_26 | Passive | Line | Right | 0 mils | 2900
1 | C12 | NC_27 | Passive | Line | Right | 0 mils | 3000
1 | C13 | NC_28 | Passive | Line | Right | 0 mils | 3100
1 | C14 | NC_29 | Passive | Line | Right | 0 mils | 3200
1 | D1 | NC_30 | Passive | Line | Right | 0 mils | 3300
1 | D2 | NC_31 | Passive | Line | Right | 0 mils | 3400
1 | D3 | NC_32 | Passive | Line | Right | 0 mils | 3500
1 | D4 | NC_33 | Passive | Line | Right | 0 mils | 3600
1 | D12 | NC_34 | Passive | Line | Right | 0 mils | 3700
1 | D13 | NC_35 | Passive | Line | Right | 0 mils | 3800
1 | D14 | NC_36 | Passive | Line | Right | 0 mils | 3900
1 | E1 | NC_37 | Passive | Line | Right | 0 mils | 4000
1 | E2 | NC_38 | Passive | Line | Right | 0 mils | 4100
1 | E3 | NC_39 | Passive | Line | Right | 0 mils | 4200
1 | E12 | NC_40 | Passive | Line | Right | 0 mils | 4300
1 | E13 | NC_41 | Passive | Line | Right | 0 mils | 4400
1 | E14 | NC_42 | Passive | Line | Right | 0 mils | 4500
1 | F1 | NC_43 | Passive | Line | Right | 0 mils | 4600
1 | F2 | NC_44 | Passive | Line | Right | 0 mils | 4700
1 | F3 | NC_45 | Passive | Line | Right | 0 mils | 4800
1 | F12 | NC_46 | Passive | Line | Right | 0 mils | 4900
1 | F13 | NC_47 | Passive | Line | Right | 0 mils | 5000
1 | F14 | NC_48 | Passive | Line | Right | 0 mils | 5100
1 | G1 | NC_49 | Passive | Line | Right | 0 mils | 5200
1 | G2 | NC_50 | Passive | Line | Right | 0 mils | 5300
1 | G12 | NC_51 | Passive | Line | Right | 0 mils | 5400
1 | G13 | NC_52 | Passive | Line | Right | 0 mils | 5500
1 | G14 | NC_53 | Passive | Line | Right | 0 mils | 5600
1 | H1 | NC_54 | Passive | Line | Right | 0 mils | 5700
1 | H2 | NC_55 | Passive | Line | Left | 1000 mils | 400
1 | H3 | NC_56 | Passive | Line | Left | 1000 mils | 500
1 | H12 | NC_57 | Passive | Line | Left | 1000 mils | 600
1 | H13 | NC_58 | Passive | Line | Left | 1000 mils | 700
1 | H14 | NC_59 | Passive | Line | Left | 1000 mils | 800
1 | J1 | NC_60 | Passive | Line | Left | 1000 mils | 900
1 | J2 | NC_61 | Passive | Line | Left | 1000 mils | 1000
1 | J3 | NC_62 | Passive | Line | Left | 1000 mils | 1100
1 | J12 | NC_63 | Passive | Line | Left | 1000 mils | 1200
1 | J13 | NC_64 | Passive | Line | Left | 1000 mils | 1300
1 | J14 | NC_65 | Passive | Line | Left | 1000 mils | 1400
1 | K1 | NC_66 | Passive | Line | Left | 1000 mils | 1500
1 | K2 | NC_67 | Passive | Line | Left | 1000 mils | 1600
1 | K3 | NC_68 | Passive | Line | Left | 1000 mils | 1700
1 | K12 | NC_69 | Passive | Line | Left | 1000 mils | 1800
1 | K13 | NC_70 | Passive | Line | Left | 1000 mils | 1900
1 | K14 | NC_71 | Passive | Line | Left | 1000 mils | 2000
1 | L1 | NC_72 | Passive | Line | Left | 1000 mils | 2100
1 | L2 | NC_73 | Passive | Line | Left | 1000 mils | 2200
1 | L3 | NC_74 | Passive | Line | Left | 1000 mils | 2300
1 | L12 | NC_75 | Passive | Line | Left | 1000 mils | 2400
1 | L13 | NC_76 | Passive | Line | Left | 1000 mils | 2500
1 | L14 | NC_77 | Passive | Line | Left | 1000 mils | 2600
1 | M1 | NC_78 | Passive | Line | Left | 1000 mils | 2700
1 | M2 | NC_79 | Passive | Line | Left | 1000 mils | 2800
1 | M3 | NC_80 | Passive | Line | Left | 1000 mils | 2900
1 | M7 | NC_81 | Passive | Line | Left | 1000 mils | 3000
1 | M8 | NC_82 | Passive | Line | Left | 1000 mils | 3100
1 | M9 | NC_83 | Passive | Line | Left | 1000 mils | 3200
1 | M10 | NC_84 | Passive | Line | Left | 1000 mils | 3300
1 | M11 | NC_85 | Passive | Line | Left | 1000 mils | 3400
1 | M12 | NC_86 | Passive | Line | Left | 1000 mils | 3500
1 | M13 | NC_87 | Passive | Line | Left | 1000 mils | 3600
1 | M14 | NC_88 | Passive | Line | Left | 1000 mils | 3700
1 | N1 | NC_89 | Passive | Line | Left | 1000 mils | 3800
1 | N3 | NC_90 | Passive | Line | Left | 1000 mils | 3900
1 | N6 | NC_91 | Passive | Line | Left | 1000 mils | 4000
1 | N7 | NC_92 | Passive | Line | Left | 1000 mils | 4100
1 | N8 | NC_93 | Passive | Line | Left | 1000 mils | 4200
1 | N9 | NC_94 | Passive | Line | Left | 1000 mils | 4300
1 | N10 | NC_95 | Passive | Line | Left | 1000 mils | 4400
1 | N11 | NC_96 | Passive | Line | Left | 1000 mils | 4500
1 | N12 | NC_97 | Passive | Line | Left | 1000 mils | 4600
1 | N13 | NC_98 | Passive | Line | Left | 1000 mils | 4700
1 | N14 | NC_99 | Passive | Line | Left | 1000 mils | 4800
1 | P1 | NC_100 | Passive | Line | Left | 1000 mils | 4900
1 | P2 | NC_101 | Passive | Line | Left | 1000 mils | 5000
1 | P8 | NC_102 | Passive | Line | Left | 1000 mils | 5100
1 | P9 | NC_103 | Passive | Line | Left | 1000 mils | 5200
1 | P11 | NC_104 | Passive | Line | Left | 1000 mils | 5300
1 | P12 | NC_105 | Passive | Line | Left | 1000 mils | 5400
1 | P13 | NC_106 | Passive | Line | Left | 1000 mils | 5500
1 | P14 | NC_107 | Passive | Line | Left | 1000 mils | 5600

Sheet: Sheet2
 | Pin | Name | Type | Symbol | Align | x | y
1 | M6 | CLK | Passive | Line | Left | 100 | 400
1 | M5 | CMD | Passive | Line | Left | 1000 | 500
1 | A3 | DAT0 | Passive | Line | Right | 0 mils | 200 mils
1 | A4 | DAT1 | Passive | Line | Right | 0 mils | 300 mils
1 | A5 | DAT2 | Passive | Line | Right | 0 mils | 400 mils
1 | B2 | DAT3 | Passive | Line | Right | 0 mils | 500
1 | B3 | DAT4 | Passive | Line | Right | 0 mils | 600
1 | B4 | DAT5 | Passive | Line | Right | 0 mils | 700
1 | B5 | DAT6 | Passive | Line | Right | 0 mils | 800
1 | B6 | DAT7 | Passive | Line | Right | 0 mils | 900
1 | H5 | DATA_STROBE | Passive | Line | Right | 0 | 1100
1 | A7 | RFU_1 | Passive | Line | Left | 1000 | 700
1 | K7 | RFU_10 | Passive | Line | Left | 1000 | 1600
1 | K10 | RFU_11 | Passive | Line | Left | 1000 | 1700
1 | P7 | RFU_12 | Passive | Line | Left | 1000 | 1800
1 | P10 | RFU_13 | Passive | Line | Left | 1000 | 1900
1 | E5 | RFU_2 | Passive | Line | Left | 1000 | 800
1 | E8 | RFU_3 | Passive | Line | Left | 1000 | 900
1 | E9 | RFU_4 | Passive | Line | Left | 1000 | 1000
1 | E10 | RFU_5 | Passive | Line | Left | 1000 | 1100
1 | F10 | RFU_6 | Passive | Line | Left | 1000 | 1200
1 | G3 | RFU_7 | Passive | Line | Left | 1000 | 1300
1 | G10 | RFU_8 | Passive | Line | Left | 1000 | 1400
1 | K6 | RFU_9 | Passive | Line | Left | 1000 | 1500
1 | K5 | RST_N | Passive | Line | Right | 0 mils | 0
1 | E6 | VCC_1 | Passive | Line | Bottom | 200 | 0
1 | F5 | VCC_2 | Passive | Line | Bottom | 300 | 0
1 | J10 | VCC_3 | Passive | Line | Bottom | 400 | 0
1 | K9 | VCC_4 | Passive | Line | Bottom | 500 | 0
1 | C6 | VCCQ_1 | Passive | Line | Bottom | 700 | 0
1 | M4 | VCCQ_2 | Passive | Line | Bottom | 800 | 0
1 | N4 | VCCQ_3 | Passive | Line | Bottom | 900 | 0
1 | P3 | VCCQ_4 | Passive | Line | Bottom | 1000 | 0
1 | P5 | VCCQ_5 | Passive | Line | Bottom | 1100 | 0
1 | C2 | VDDI | Passive | Line | Left | 200 | 1000
1 | A6 | VSS_1 | Passive | Line | Top | 200 | 2000
1 | E7 | VSS_2 | Passive | Line | Top | 300 | 2000
1 | G5 | VSS_3 | Passive | Line | Top | 400 | 2000
1 | H10 | VSS_4 | Passive | Line | Top | 500 | 2000
1 | J5 | VSS_5 | Passive | Line | Top | 600 | 2000
1 | K8 | VSS_6 | Passive | Line | Top | 700 | 2000
1 | C4 | VSSQ_1 | Passive | Line | Top | 900 | 2000
1 | N2 | VSSQ_2 | Passive | Line | Top | 1000 | 2000
1 | N5 | VSSQ_3 | Passive | Line | Top | 1100 | 2000
1 | P4 | VSSQ_4 | Passive | Line | Top | 1200 | 2000
1 | P6 | VSSQ_5 | Passive | Line | Top | 1300 | 2000

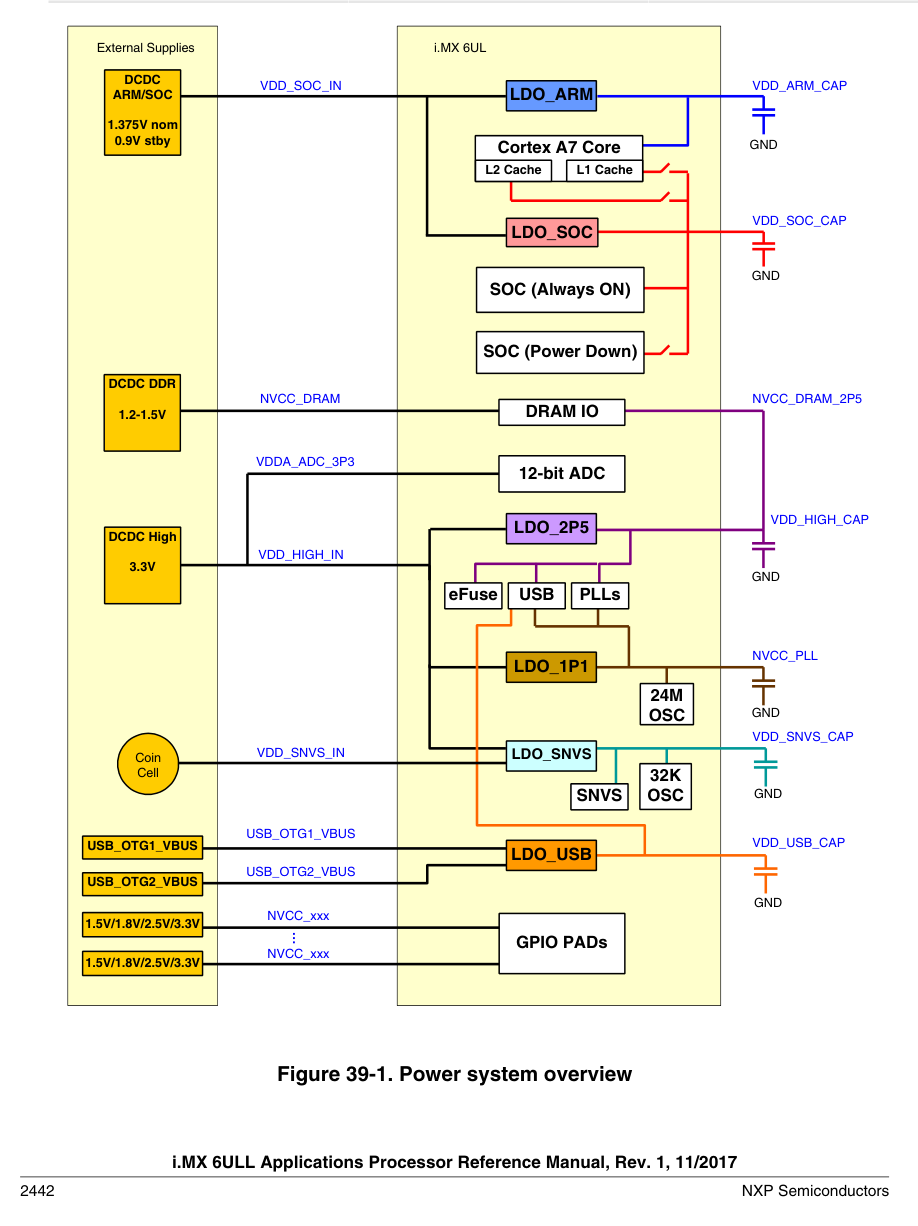
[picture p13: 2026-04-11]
Design Files/Images/iMX6_PMU_diagram.png

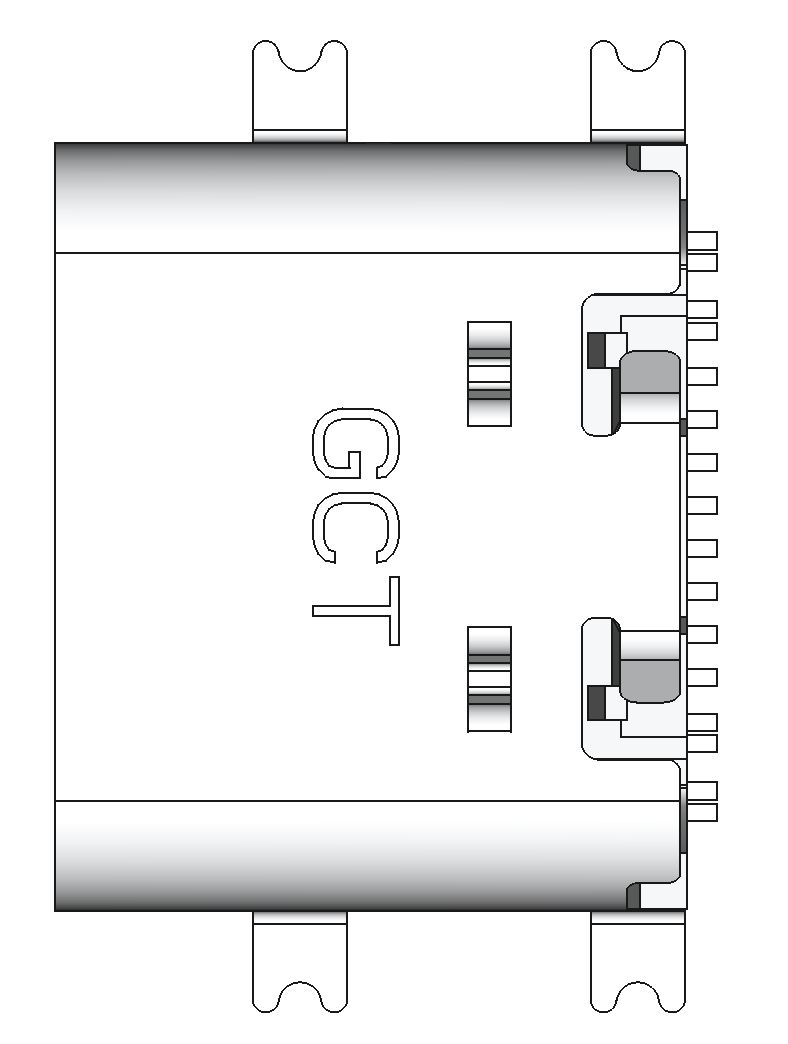
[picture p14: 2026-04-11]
Design Files/Images/usbc.png

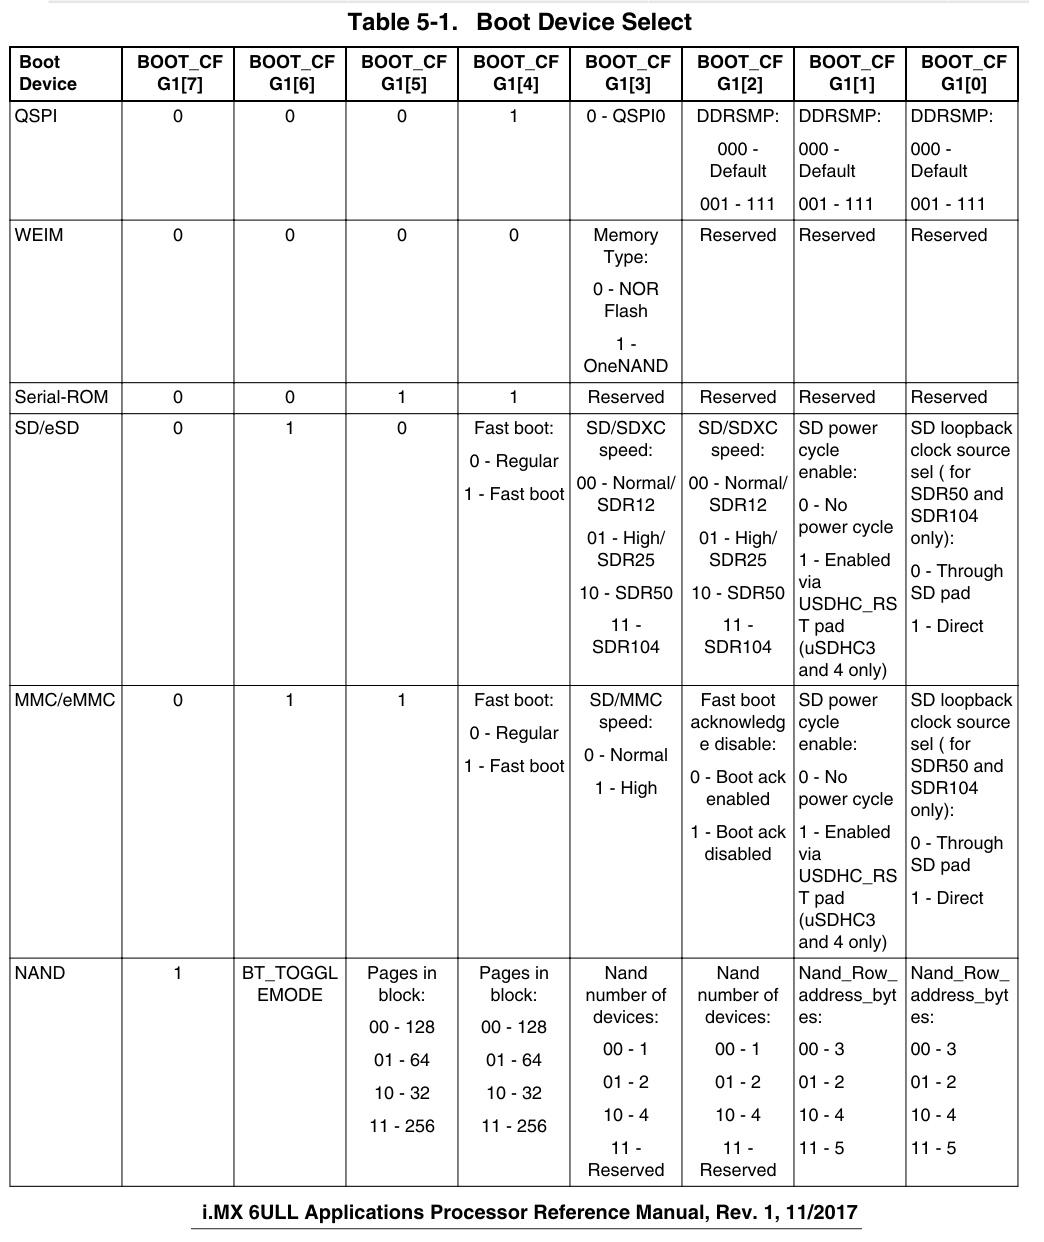
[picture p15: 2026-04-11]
Design Files/Images/BOOT_CFG_map.png

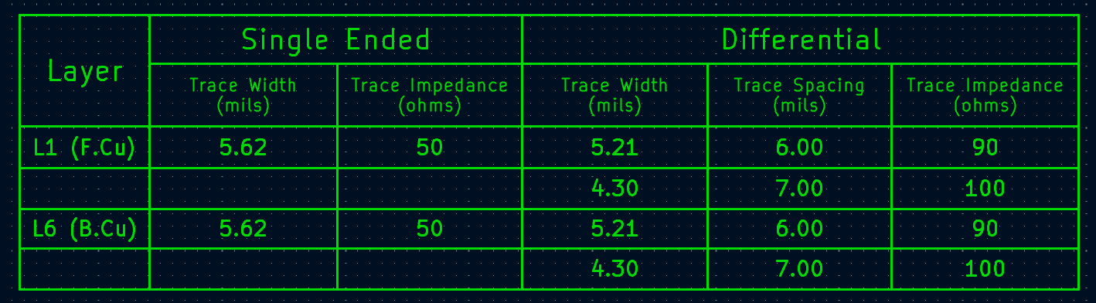
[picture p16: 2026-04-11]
Production/PCB Rev 1/JLCPCB_Rev1_Build/iMX6_BareBones_Rev1_Gerber_JLCproduction/YG/IMX6_BAREBONES_REV1_GERBERS_Y12(REPLACEFILE)/iMX6_BareBone_Rev1_Gerbers_042226/impedance_spec.png

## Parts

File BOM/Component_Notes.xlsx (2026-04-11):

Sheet: Sheet1
Category | Manufacturer | MPN | Symbol | Footprint | 3D Model | Notes | Qty
DRAM | Micron | MT41K256M16TW-107 | UltraLibrarian | UltraLibrarian | UltraLibrarian |  | 1
Processor | NXP | MCIMX6Y2DVM09AB | NXP | NXP | NXP | 900MHz | 1
SD Card Connector | GCT | MEM2090-00-145-00-A | SnapMagic | SnapMagic | SnapMagic |  | 1
SD ESD (data) | Nexperia | PUSB3AB6Z | SnapMagic | SnapMagic | SnapMagic |  | 1
TVS | Onsemi | ESD9B5.0ST5G | Kicad | Kicad | Kicad |  | 2
USB-C Connector | GCT | USB4110-GF-A | SnapMagic | SnapMagic | SnapMagic |  | 2
LDO | Texas Instruments | TLV76033DBZR | TI | TI | TI | 3.3V STDBY, LDO | 1
LDO | Texas Instruments | TLV75718PDBVR | TI | TI | TI | 1.8V, LDO | 1
Load Switch | Onsemi | NCP380HMUAJAATBG | Onsemi | Onsemi | Onsemi |  | 1
Buck 3.3V, 1.4V | MPS | MP2182GTL-Z | Digikey | Digikey | Digikey |  | 2
Buck DDR | Diodes Inc | AP3401KTTR-G1 | Diodes Inc | Diodes Inc | Diodes Inc |  | 1
SPI Flash | Renesas | AT25SF321B-SSHB-T | Renesas | Renesas | Renesas |  | 1
USB to UART | Silicon Labs | CP2102N-A02-GQFN20 | SnapMagic | SnapMagic | SnapMagic |  | 1
Level Shifter | Texas Instruments | TXS0102DCUR | TI | TI | TI |  | 1
Crystal 24MHz | Epson | TSX-3225 24.0000MF15X-AC3 | SnapMagic | SnapMagic | SnapMagic |  | 1
Crystal 32kHz | Epson | FC-135 32.7680KA-K0 | Mouser | Mouser | Mouser |  | 1
Dip Switch 2-pos | Omron | A6H-2101 | Custom | Kicad | Kicad |  | 1
Dip Switch 4-pos | Omron | A6H-4101 | Custom | Kicad | Kicad |  | 1
Voltage supervisor | Diodes Inc | APX803S-26SR-7 | Diodes Inc | Diodes Inc | Diodes Inc | Voltage supervisor | 1
eMMC | Macronix | MX52LM04A11XSI | Mouser | Mouser | Mouser |  | 1
USB ESD Diodes | Littelfuse | SP0503BAHTG | Littelfuse | Littelfuse | Littelfuse | Recommended in CP2102 datasheet | 2
RJ45 | Wurth | 7499010121A | Wurth | Wurth | Wurth |  | 1
Ethernet Transceiver | Microchip | KSZ8081RNBIA-TR | Microchip | Microchip | Microchip |  | 1
USB A Receptacle | Wurth | 61400416021 | UltraLibrarian | SnapMagic | SnapMagic |  | 1
USB Load Switch | Microchip | MIC2025-1YMM-TR | Microchip | Microchip | Microchip |  | 1
CAN Transceiver | NXP | TJA1042T/3 | NXP | NXP | NXP |  | 2
CMC for CAN | Murata | DLW43SH510XK2 | SnapMagic | SnapMagic | SnapMagic |  | 1
3A fuse | Bourns | SF-1206S300-2 | Kicad | Kicad | Kicad |  | 1
1.5A fuse | Bourns | SF-1206S150-2 | Kicad | Kicad | Kicad |  | 1
0.8A fuse | Bourns | SF-1206S080-2 | Kicad | Kicad | Kicad |  | 8
USB OVLO | NXP | NX20P5090UK | NXP | NXP | NXP |  | 1
Inductor | Wurth | 74438322010 | Kicad | Kicad | Wurth | Inductor of P3V3 | 0
Inductor | Wurth | 74438323022 | Kicad | Kicad | Kicad | Inductor for P1V4_SOC/P1V35_DRAM | 0
Inductor | Wurth | 74437324010 | Kicad | SnapMagic | Wurth | Inductor of P3V3 | 1
Inductor | Wurth | 74437324022 | Kicad | SnapMagic | Wurth | Inductor for P1V4_SOC/P1V35_DRAM | 2
And gates | Nexperia | 74LVC2G08GT,115 | Digikey | Digikey | Digikey |  | 1
Button | E Switch | 800SP9B10M6QE | Custom | Custom | E Switch |  | 1
2x9 Header | Sullins | PPPC092LFBN-RC | Kicad | Kicad | Sullins |  | 1
2x10 Header | Sullins | PPPC102LFBN-RC | Kicad | Kicad | Sullins |  | 1
2x12 Header | Sullins | PPPC122LFBN-RC
2x4 Header | Sullins | PPPC042LFBN-RC | Kicad | Kicad | Sullins |  | 1
Dual LED green | Kingbright | WP934MD/2GD | Digikey | SnapMagic | SnapMagic |  | 1
Dual buffer | Texas Instruments | SN74LVC2G34DCKR | TI | TI | TI |  | 1
Dual NPN | Onsemi | MBT3904DW1T3G | Onsemi | Onsemi | Onsemi |  | 1
0.125A fuse | Littelfuse | 0466.125NRHF | Kicad | Kicad | Kicad |  | 3
JTAG Connector | Samtec | FTSH-105-01-L-DV-K | Kicad | Samtec | Samtec |  | 1
Test Point Hook | Keystone | 5015 | SnapMagic | SnapMagic | SnapMagic
USB 2.0 ESD Diodes | ST Micro | USBLC6-2SC6 | ST Micro | ST Micro | ST Micro |  | 2

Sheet: Sheet2
VDD_SOC_IN | 1.4
VDD_ARM_CAP | 1.275
VDD_SOC_CAP | 1.275

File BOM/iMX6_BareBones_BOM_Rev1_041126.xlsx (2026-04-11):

Item Number | Designator | Qty | Manufacturer | Manufacturer Part Number | Description/Value | Footprint | Type | DNP | Package | Power | Tolerance | Voltage | Temperature Coefficients
1 | C1,C24,C26,C82,C107,C108,C112,C118,C120,C122,C126,C129,C131,C133,C140,C142,C144 | 17 | Murata | GRM188Z71A106KA73 | 10uF | Capacitor_SMD:C_0603_1608Metric | SMD |  | 603 |  | 10% | 10V | X7R
2 | C2,C3,C5,C8,C9,C10,C11,C12,C13,C14,C15,C16,C17,C18,C19,C20,C22,C23,C34,C35,C37,C40,C42,C44,C45,C48,C49,C50,C52,C53,C58,C59,C60,C61,C62,C63,C64,C65,C66,C67,C68,C69,C70,C71,C72,C84,C85,C88,C89,C91,C110,C116,C123,C128,C146,C148,C149 | 57 | Murata | GRM155R71C224KA12 | 0.22uF | Capacitor_SMD:C_0402_1005Metric | SMD |  | 402 |  | 10% | 16V | X7R
3 | C4,C21,C25,C51,C76,C77,C113 | 7 | Murata | GRM188R61A226ME15 | 22uF | Capacitor_SMD:C_0603_1608Metric | SMD |  | 603 |  | 20% | 10V | X5R
4 | C6,C7,C33,C46 | 4 | Murata | GRM155R61A475MEA | 4.7uF | Capacitor_SMD:C_0402_1005Metric | SMD |  | 402 |  | 20% | 10V | X5R
5 | C27,C28,C117,C125 | 4 | Murata | GJM1555C1H220FB01 | 22pF | Capacitor_SMD:C_0402_1005Metric | SMD |  | 402 |  | 1% | 50V | C0G
6 | C29,C30,C47,C73,C74,C75,C78,C79,C83,C92,C94,C97,C106,C109,C114,C115,C119,C121,C124,C127,C130,C132,C134,C135,C139,C141,C143,C145,C147,C150 | 30 | Murata | GRM155R71C104KA88 | 0.1uF | Capacitor_SMD:C_0402_1005Metric | SMD |  | 402 |  | 10% | 16V | X7R
7 | C31,C32 | 2 | Murata | GJM1555C1H180FB01 | 16pF | Capacitor_SMD:C_0402_1005Metric | SMD |  | 402 |  | 1% | 50V | C0G
8 | C36 | 1 | Murata | GRM21BR61A476ME15 | 47uF | Capacitor_SMD:C_0805_2012Metric | SMD |  | 805 |  | 20% | 10V | X5R
9 | C38,C41,C43,C80 | 4 | Murata | GRM155Z71A225KE44 | 2.2uF | Capacitor_SMD:C_0402_1005Metric | SMD |  | 402 |  | 10% | 10V | X7R
10 | C39,C81,C90,C93,C95,C96,C98,C105,C138 | 9 | Murata | GRM155Z71A105KE01 | 1uF | Capacitor_SMD:C_0402_1005Metric | SMD |  | 402 |  | 10% | 10V | X7R
11 | C54,C55 | 2 | Murata | GJM1555C1H2R2WB01 | 2.2pF | Capacitor_SMD:C_0402_1005Metric | SMD | DNP | 402 |  | Â±0.05pF | 50V | C0G
12 | C56,C57 | 2 | Murata | GJM1555C1H2R2WB01 | 2.2pF | Capacitor_SMD:C_0402_1005Metric | SMD |  | 402 |  | Â±0.05pF | 50V | C0G
13 | C86 | 1 | Murata | GRM21BZ71H475ME15 | 4.7uF | Capacitor_SMD:C_0805_2012Metric | SMD |  | 805 |  | 10% | 50V | X7R
14 | C87 | 1 | Kemet | EEV107M035S9HAA | 100uF | Capacitor_SMD:CP_Elec_6.3x7.7 | SMD |  | 6.3x7.7 |  | 20% | 35V
15 | C99,C100 | 2 | Murata | GRM1555CYA103GE01 | 0.01uF | Capacitor_SMD:C_0402_1005Metric | SMD | DNP | 402 |  | 2% | 35V | C0G
16 | C101,C102,C103,C104 | 4 | Murata | GRM1555C1H560JA01 | 56pF | Capacitor_SMD:C_0402_1005Metric | SMD |  | 402 |  | 5% | 50V | C0G
17 | C111 | 1 | Murata | GRM1555C1H222GA01 | 2.2nF | Capacitor_SMD:C_0402_1005Metric | SMD |  | 402 |  | 2% | 50V | C0G
18 | C136,C137 | 2 | Murata | GRM155R71C104KA88 | 0.1uF | Capacitor_SMD:C_0402_1005Metric | SMD | DNP | 402 |  | 10% | 16V | X7R
19 | D1,D2,D7 | 3 | Onsemi | ESD9B5.0ST5G | ESD9B5.0ST5G | Diode_SMD:D_SOD-923 | SMD
20 | D4 | 1 | Lite-on | LTST-C170GKT | LTST-C170GKT | LED_SMD:LED_0805_2012Metric | SMD |  | 805
21 | D5 | 1 | Lite-on | LTST-C170KRKT | LTST-C170KRKT | LED_SMD:LED_0805_2012Metric | SMD |  | 805
22 | D6 | 1 | Littelfuse | SP0503BAHTG | SP0503BAHTG | a1wolfe:SP0503BAHTG | SMD
23 | D8 | 1 | Kingbright | WP934MD/2GD | WP934MD/2GD | a1wolfe:LED_WP934MD_2GD | thru-hole
24 | F1,F3,F4,F5,F6,F7,F8,F11,F12,F13,F14,F15,F16,F19 | 14 | Bourns | SF-1206S080-2 | SF-1206S080-2 | Fuse:Fuse_1206_3216Metric | SMD |  | 1206
25 | F2,F17,F18 | 3 | Bourns | SF-1206S080-2 | SF-1206S080-2 | Fuse:Fuse_1206_3216Metric | SMD | DNP | 1206
26 | F9 | 1 | Bourns | SF-1206S300-2 | SF-1206S300-2 | Fuse:Fuse_1206_3216Metric | SMD |  | 1206
27 | F10 | 1 | Bourns | SF-1206S150-2 | SF-1206S150-2 | Fuse:Fuse_1206_3216Metric | SMD |  | 1206
28 | J1 | 1 | Samtec | FTSH-105-01-L-DV-K | FTSH-105-01-L-DV-K | a1wolfe:SAMTEC_FTSH-105-XX-X-DV | SMD
29 | J2 | 1 | GCT | USB4110-GF-A | USB4110-GF-A | a1wolfe:GCT_USB4110GFA | thru-hole
30 | J3 | 1 | GCT | MEM2090-00-145-00-A | MEM2090-00-145-00-A | a1wolfe:GCT_MEM2090-00-145-00-A_REVA | SMD
31 | J4 | 1 | Wurth | 7499010121A | 7499010121A | a1wolfe:T_Wurth_WE-RJ45LAN_7499010121A | thru-hole
32 | J5 | 1 | Wurth | 61400416021 | 61400416021 | a1wolfe:USBArec_61400416021 | thru-hole
33 | J6 | 1 | GCT | USB4110-GF-A | USB4110 | a1wolfe:GCT_USB4110GFA | SMD
34 | J7 | 1 | Sullins | PPPC092LFBN-RC | PPPC092LFBN-RC | a1wolfe:PinSocket_2x09_P2.54mm_Vertical (Sullins PPPC092LFBN-RC) | thru-hole
35 | J8 | 1 | Sullins | PPPC042LFBN-RC | PPPC042LFBN-RC | a1wolfe:PinSocket_2x04_P2.54mm_Vertical ( Sullins PPPC042LFBN-RC) | thru-hole
36 | J9 | 1 | Sullins | PPPC122LFBN-RC | PPPC122LFBN-RC | a1wolfe:PinSocket_2x12_P2.54mm_Vertical (Sullins PPPC122LFBN-RC) | thru-hole
37 | L1,L2 | 2 | Murata | DLW43SH510XK2K | DLW43SH510XK2K | a1wolfe:FIL_DLW43SH510XK2K | SMD | DNP
38 | L3 | 1 | Wurth | 74437324010 | 1uH | a1wolfe:WE-LHMI_4020 | SMD
39 | L4,L5 | 2 | Wurth | 74437324022 | 2.2uH | a1wolfe:WE-LHMI_4020 | SMD
40 | Q1 | 1 | Onsemi | MBT3904DW1T3G | MBT3904DW1T3G | a1wolfe:DualNPN_MBT3904DW1T3G_SOT65P210X110-6N | SMD
41 | R1,R57,R91 | 3 | Yageo | RT0402BRD07240RL | 240 | Resistor_SMD:R_0402_1005Metric | SMD |  | 402 | 1/16W | 0.10%
42 | R2,R3,R14,R28,R29,R30,R31,R32,R33,R34,R35,R36,R37,R38,R39,R40,R42,R43,R44,R45,R46,R47,R48,R49,R50,R51,R61,R69,R70,R71,R72,R73,R74,R75,R82,R92,R172,R174,R241,R245,R254,R256,R257,R261,R281 | 45 | Yageo | RC0402FR-7W10KL | 10k | Resistor_SMD:R_0402_1005Metric | SMD |  | 402 | 1/8W | 1%
43 | R4,R5,R6,R7,R106,R107,R121,R123,R127,R129,R131,R135,R139,R142,R167,R277,R278 | 17 | Yageo | RC0402FR-7W1KL | 1k | Resistor_SMD:R_0402_1005Metric | SMD |  | 402 | 1/8W | 1%
44 | R8,R9,R10,R11,R12,R13,R15,R16,R17,R18,R19,R20,R21,R22,R23,R24,R25,R26,R27,R41,R171,R175,R246,R247,R252,R253 | 26 | Yageo | RC0402FR-7W10KL | 10k | Resistor_SMD:R_0402_1005Metric | SMD | DNP | 402 | 1/8W | 1%
45 | R52,R58,R59,R62,R63,R64,R65,R66,R67,R68,R76,R77,R78,R79,R80,R81,R85,R86,R99,R104,R108,R109,R110,R111,R112,R113,R114,R115,R116,R143,R144,R145,R146,R147,R148,R149,R150,R151,R152,R153,R154,R155,R156,R157,R158,R159,R160,R161,R164,R166,R168,R170,R173,R178,R179,R180,R181,R184,R187,R188,R189,R190,R191,R192,R193,R194,R195,R196,R197,R198,R199,R200,R201,R202,R203,R204,R205,R206,R207,R208,R209,R210,R211,R212,R213,R214,R215,R216,R217,R218,R219,R220,R221,R222,R223,R224,R225,R226,R227,R228,R229,R230,R231,R232,R233,R234,R235,R236,R248,R262,R263,R267,R269,R270,R273,R274 | 116 | Yageo | RC0402JR-070RL | 0 | Resistor_SMD:R_0402_1005Metric | SMD |  | 402 | 1/16W | Jumper
46 | R53 | 1 | Vishay Dale | MCS0402MD1004BE000 | 1M | Resistor_SMD:R_0402_1005Metric | SMD | DNP | 402 | 1/16W | 0.10%
47 | R54,R55,R117 | 3 | Panasonic Electronic Components | ERA-2AEB152X | 1.5k | Resistor_SMD:R_0402_1005Metric | SMD |  | 402 | 1/16W | 0.10%
48 | R56,R118,R124,R132,R136,R140 | 6 | Yageo | RC0402FR-074K7L | 4.7k | Resistor_SMD:R_0402_1005Metric | SMD |  | 402 | 1/16W | 1%
49 | R60,R162,R163,R169,R185,R186,R264,R265,R266 | 9 | Yageo | RC0402JR-070RL | 0 | Resistor_SMD:R_0402_1005Metric | SMD | DNP | 402 | 1/16W | Jumper
50 | R83 | 1 | Yageo | RC0402FR-0747K5L | 47.5k | Resistor_SMD:R_0402_1005Metric | SMD |  | 402 | 1/16W | 1%
51 | R84 | 1 | Yageo | RC0402FR-0722K1L | 22.1k | Resistor_SMD:R_0402_1005Metric | SMD |  | 402 | 1/16W | 1%
52 | R87,R88,R237,R238 | 4 | Yageo | RT0402BRD075K1L | 5.1k | Resistor_SMD:R_0402_1005Metric | SMD |  | 402 | 1/16W | 0.10%
53 | R89,R90,R93 | 3 | Vishay Dale | RCC0402470RFKED | 470 | Resistor_SMD:R_0402_1005Metric | SMD |  | 402 | 1/8W | 1%
54 | R94,R95,R96,R97,R98,R100,R101,R102,R103,R239 | 10 | Vishay Dale | MCS0402MD1004BE000 | 1M | Resistor_SMD:R_0402_1005Metric | SMD |  | 402 | 1/16W | 0.10%
55 | R105 | 1 | Vishay Dale | CRCW04026K49FKED | 6.49k | Resistor_SMD:R_0402_1005Metric | SMD |  | 402 | 1/10W | 1%
56 | R119,R125,R133,R137,R141 | 5 | Yageo | RC0402FR-7W1KL | 1k | Resistor_SMD:R_0402_1005Metric | SMD | DNP | 402 | 1/8W | 1%
57 | R120,R122,R126,R128,R130,R134,R138,R271,R272 | 9 | Yageo | RC0402FR-074K7L | 4.7k | Resistor_SMD:R_0402_1005Metric | SMD | DNP | 402 | 1/16W | 1%
58 | R176,R177,R182,R183 | 4 | KOA Speer Electronics, Inc. | RK73H2ATTD62R0F | 62 | Resistor_SMD:R_0805_2012Metric | SMD |  | 805 | 1/4W | 1%
59 | R240 | 1 | Yageo | RT0402BRD07182KL | 182k | Resistor_SMD:R_0402_1005Metric | SMD |  | 402 | 1/16W | 0.10%
60 | R243 | 1 | Yageo | RT0402BRD07200KL | 200k | Resistor_SMD:R_0402_1005Metric | SMD |  | 402 | 1/16W | 0.10%
61 | R244 | 1 | Yageo | RT0402BRD0744K2L | 44.2k | Resistor_SMD:R_0402_1005Metric | SMD |  | 402 | 1/16W | 0.10%
62 | R249,R250,R258,R259,R279,R280,R282 | 7 | Yageo | RT0402BRE07100KL | 100k | Resistor_SMD:R_0402_1005Metric | SMD |  | 402 | 1/16W | 0.10%
63 | R251 | 1 | Yageo | RT0402BRD0775KL | 75k | Resistor_SMD:R_0402_1005Metric | SMD |  | 402 | 1/16W | 0.10%
64 | R260 | 1 | Stackpole Electronics Inc | RNCF0402BTE80K0 | 80k | Resistor_SMD:R_0402_1005Metric | SMD |  | 402 | 1/10W | 0.10%
65 | R275,R276 | 2 | Vishay Dale | CRCW080543R0FKEA | 43 | Resistor_SMD:R_0805_2012Metric | SMD |  | 805 | 1/4W | 1%
66 | SW1 | 1 | Omron | A6H-2101 | A6H-2101 | Button_Switch_SMD:SW_DIP_SPSTx02_Slide_Omron_A6H-2101_W6.15mm_P1.27mm | SMD
67 | SW2 | 1 | Omron | A6H-4101 | A6H-4101 | Button_Switch_SMD:SW_DIP_SPSTx04_Slide_Omron_A6H-4101_W6.15mm_P1.27mm | SMD
68 | SW3 | 1 | E Switch | 800SP9B10M6QE | 800SP9B10M6QE | a1wolfe:800SP9B10M6QE | thru-hole
69 | TP1,TP2,TP26,TP27,TP28,TP29,TP30,TP31,TP32,TP33,TP34,TP35,TP36,TP37,TP38,TP39,TP40,TP51,TP58,TP65,TP66 | 21 |  |  | TestPoint | a1wolfe:TestPoint_Pad_D30mil | SMD
70 | TP5,TP6,TP7,TP9,TP11,TP13,TP15,TP16,TP17,TP19,TP21,TP23,TP47,TP48,TP49,TP50,TP53,TP54,TP55,TP56 | 20 |  |  | TestPoint | a1wolfe:TestPoint_Pad_D18mil | SMD
71 | TP41,TP42,TP43,TP44,TP45,TP46,TP52,TP57 | 8 | Keystone | 5015 | TestPoint | a1wolfe:KEYSTONE_5015 | SMD
72 | U1 | 1 | NXP | MCIMX6Y2DVM09AB | MCIMX6Y2DVM09AB | a1wolfe:imx6ull_BGA289C80P17X17_1400X1400X132 | SMD
73 | U2 | 1 | Nexperia | PUSB3AB6Z | PUSB3AB6Z | a1wolfe:IC_PUSB3AB6Z_ESD-SD | SMD
74 | U3 | 1 | Renesas | AT25SF321B-SSHB-T | AT25SF321B-SSHB-T | a1wolfe:QSPI_flash_AT25SF321B_SOIC127P600X175-8N | SMD
75 | U4 | 1 | NXP | NX20P5090UK | NX20P5090UK | a1wolfe:NX20P5090UK | SMD
76 | U5 | 1 | Micron | MT41K256M16TW-107 | MT41K256M16TW-107 | a1wolfe:MT41K_BGA96C80P9X16_1400X800X120 | SMD
77 | U6 | 1 | Macronix | MX52LM04A11XSI | MX52LM04A11XSI | a1wolfe:eMMC_BGA153C50P14X14_1150X1300X80 | SMD
78 | U7 | 1 | Microchip | KSZ8081RNBIA-TR | KSZ8081RNBIA-TR | a1wolfe:KSZ8081RNB_QFN32 | SMD
79 | U8 | 1 | Silicon Labs | CP2102N-A02-GQFN20 | CP2102N-A02-GQFN20 | a1wolfe:CP2102N_WFQFN-20 | SMD |  | WFQFN-20 Silicon Labs
80 | U9 | 1 | Microchip | MIC2025-1YMM | MIC2025-1YMM | a1wolfe:MIC2025_MSOP-8_MM_MCH | SMD
81 | U10,U11 | 2 | NXP | TJA1042T/3 | TJA1042T/3 | a1wolfe:TJA1042T_SOIC127P600X175-8N | SMD
82 | U12 | 1 | Texas Instruments | TLV76033DBZR | TLV76033DBZR | a1wolfe:TLV76033 | SMD
83 | U13 | 1 | Monolithic Power Systems | MP2182GTL-Z | MP2182GTL-Z | a1wolfe:SOT583_MP2182_MNP | SMD
84 | U14,U15 | 2 | Diodes Incorporated | AP3401KTTR-G1 | AP3401KTTR-G1 | a1wolfe:AP3401_SOT95P280X100-6N | SMD
85 | U16 | 1 | Texas Instruments | TLV75718PDBVR | TLV75718PDBVR | a1wolfe:LTV75718 | SMD
86 | U17 | 1 | Diodes Incorporated | APX803S-26SR | APX803S-26SR | a1wolfe:APX803 | SMD
87 | U18 | 1 | Nexperia | 74LVC2G08GT | 74LVC2G08GT | a1wolfe:DualAnd_74LVC2G08GT | SMD
88 | U19 | 1 | Texas Instruments | SN74LVC2G34DCK3 | SN74LVC2G34DCK3 | a1wolfe:SN74LVC2G34_DCK6 | SMD
89 | U20 | 1 |  |  | USBLC6-2SC6 | a1wolfe:USBLC6-2SC6 | SMD
90 | Y1 | 1 | Epson | TSX-3225 24.0000MF15X-AC3 | TSX-3225 24.0000MF15X-AC3 | a1wolfe:TSX-322524.0000MF15X-AC3 | SMD
91 | Y2 | 1 | Epson | FC-135_32.7680KA | FC-135_32.7680KA | a1wolfe:FC135327680KAK0 | SMD

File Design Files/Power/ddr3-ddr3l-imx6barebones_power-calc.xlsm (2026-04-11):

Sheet: Title
File Name | : | DDR3_Power_Calc.XLSM
Revision | : | 1.02
Date | : | 2020-11-02
E-Mail | : | dramsupport@micron.com
Company | : | Micron Technology, Inc.
Description | : | Calculates the power consumed by a DDR3 and DDR3L SDRAM based on system use parameters and the device data sheet.
Limitations | :
Notes | :
Disclaimer | : | THIS SPREADSHEET IS FOR ESTIMATING PURPOSES ONLY. ANY INFORMATION PROVIDED HEREIN IS PROVIDED "AS IS" AND WITHOUT WARRANTIES OF ANY KIND. MICRON WARRANTS ONLY THAT ITS PRODUCTS COMPLY WITH MICRON'S SPECIFICATION SHEET FOR THE PRODUCT AT THE TIME OF DELIVERY; PROVIDED THAT DEVIATIONS FROM SPECIFICATIONS WHICH DO NOT MATERIALLY AFFECT FORM, FIT OR FUNCTION OF SUCH PRODUCT IN THE SYSTEM AND CONFIGURATION IN OR FOR WHICH IT IS INITIALLY INSTALLED OR QUALIFIED BY CUSTOMER SHALL NOT BE DEEMED TO CONSTITUTE FAILURE TO COMPLY WITH SUCH SPECIFICATIONS.
 |  | SEE MICRON'S STANDARD TERMS AND CONDITIONS OF SALE FOR COMPLETE WARRANTY DETAILS.
 |  | Copyright © 2007 Micron Semiconductor Products, Inc.
 |  | All rights reserved.

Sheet: Instructions
Instructions for Use
 | DDR3 Spec tab (ALL MUST BE VERIFIED FOR A SPECIFIC DRAM DATA SHEET)
 |  | Inputs are required for all densities and speed grades that may be chosen.
 |  | Enter VDD tolerance range in rows 6–7.
 |  | Enter IDD values for the speed grade under investigation in rows 9–26. Note that there are entries for both x4/x8 devices, as well as x16. Also note the two separate entries for IDD3P, depending on the mode register setting.
 |  | Timing restrictions in rows 28–36 are entered from the data sheet. These determine the test conditions for the IDD values and restrictions of normal device operation.
 | DDR3 Config tab (ALL MUST BE ENTERED TO IDENTIFY DRAM TO BE USED FOR POWER CALCULATION)
 |  | Row 7 selects which DRAM density.
 |  | Row 8 selects the number of DQs.
 |  | Row 9 selects the starting speed grade.
 |  | Row 10 selects low voltage or nominal.
 |  | Row 11 selects whether fast or slow exit is used for power-down exit.
 | DDR3 Spec tab (ALL MUST BE ENTERED FOR SPECIFIC SYSTEM)
 |  | Row 7 is the actual VDD the system is operating at. It is usually set to nominal conditions.
 |  | Row 8 is the clock rate the DRAM is operating at. This is one half of the data rate.
 |  | Row 9 is the burst length programmed in the mode register. (The model does not calculate power if burst interrupt is utilized.)
 |  | Row 10* is the amount of power that is drawn per output while driving read data from itself.
 |  | Row 11* is the amount of power that is drawn per output while terminating write data to itself.
 |  | Row 12* is the amount of power that is drawn per DQ while terminating read data at different DRAM (two or more loads).
 |  | Row 13* is the amount of power that is drawn per DQ while terminating write data at different DRAM (two or more loads).
 |  | *These are system-dependent and must be calculated. The value may be approximated with a DC calculation (calculator provided) or more accurately determined using SPICE models.
 |  | Row 15 is the time when all banks are in a precharged state. This is the amount of time when no bank has been activated.
 |  | Row 16 is the percentage of time that all that banks are precharged when the device is in power-down state. This is the percentage of time when the DRAM is using IDD2P vs. IDD2F.
 |  | Row 17 is the percentage of DRAM active time when CKE is LOW and the device is in the power-down state. This is the percentage of active time when the DRAM is using IDD3P current vs. IDD3N.
 |  | Row 19 is the average time between ACT commands to the DRAM. Under IDD0 or IDD1 conditions, this would be equal to tRC. If the DRAM is in interleaving bursts, it may be less than tRC. This value is now calculated off of page hit rate. Entering a number here will override the automatic calculation.
 |  | Row 21 is the percentage of clocks that data is read from the DRAM. This would be equal to the average read bandwidth divided by peak read bandwidth.
 |  | Row 22 is the percentage of clocks that data is written to the DRAM. This would be equal to the average read bandwidth divided by peak read bandwidth.
 |  | Row 23 is the page hit rate. 0% means there are no page hits (i.e., one read/write per each activate).
 |  | Row 24 is the percentage of clock cycles the DRAM under investigation is terminating read data from another device. It does not include time when a different DRAM on the bus may be terminating data.
 |  | Row 25 is the percentage of clock cycles the DRAM under investigation is terminating write data from another device. It does not include time when a different DRAM on the bus may be terminating data.
 | Power Calcs tab
 |  | No inputs are required for this tab. It contains some of the detail calculations that provide information into the Summary tab. It can be used as a reference for further understanding the calculator, or you may jump straight to the Summary page for the final answer.
 | Summary tab
 |  | No inputs are required for this tab. It contains a summary of the power used by the DRAM. The power is broken out between: — Power to read/write data to and from the DRAM — Power to activate the rows — Background power for standby modes and refresh

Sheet: DDR3 Spec
 |  |  |  |  |  |  |  |  |  |  |  |  |  |  |  |  |  |  |  |  |  |  |  |  |  | 4Gb, -107
 |  |  | 1Gb |  |  |  |  |  |  |  |  |  | 2Gb |  |  |  |  |  |  |  |  |  | 4Gb |  |  |  |  |  |  |  |  |  | 8Gb |  |  |  |  |  |  |  |  |  | 16Gb
Parameter | Condition | Condition | -093E | -093 | -107E | -107 | -125E | -125 | -15E | -187E | -187 | -25 | -093E | -093 | -107E | -107 | -125E | -125 | -15E | -187E | -187 | -25 | -093E | -093 | -107E | -107 | -125E | -125 | -15E | -187E | -187 | -25 | -093E | -093 | -107E | -107 | -125E | -125 | -15E | -187E | -187 | -25 | -093E | -093 | -107E | -107 | -125E | -125 | -15E | -187E | -187 | -25
 | Maximum VDD |  | 1.435 | 1.435 | 1.435 | 1.435 | 1.435 | 1.435 | 1.435 | 1.435 | 1.435 | 1.435 | 1.435 | 1.435 | 1.435 | 1.435 | 1.435 | 1.435 | 1.435 | 1.435 | 1.435 | 1.435 | 1.435 | 1.435 | 1.435 | 1.45 | 1.435 | 1.435 | 1.435 | 1.435 | 1.435 | 1.435 | 1.435 | 1.435 | 1.435 | 1.435 | 1.435 | 1.435 | 1.435 | 1.435 | 1.435 | 1.435 | 1.435 | 1.435 | 1.435 | 1.435 | 1.435 | 1.435 | 1.435 | 1.435 | 1.435 | 1.435 | V
 | Minimum VDD |  | 1.283 | 1.283 | 1.283 | 1.283 | 1.283 | 1.283 | 1.283 | 1.283 | 1.283 | 1.283 | 1.283 | 1.283 | 1.283 | 1.283 | 1.283 | 1.283 | 1.283 | 1.283 | 1.283 | 1.283 | 1.283 | 1.283 | 1.283 | 1.283 | 1.283 | 1.283 | 1.283 | 1.283 | 1.283 | 1.283 | 1.283 | 1.283 | 1.283 | 1.283 | 1.283 | 1.283 | 1.283 | 1.283 | 1.283 | 1.283 | 1.283 | 1.283 | 1.283 | 1.283 | 1.283 | 1.283 | 1.283 | 1.283 | 1.283 | 1.283 | V
IDD0 | Maximum active precharge current | x4/x8 | na | 46 | na | 43 | na | 42 | 41 | 39 | na | na | na | 46 | na | 43 | na | 42 | 41 | 39 | na | na | na | 31 | na | 62 | na | 28 | na | na | na | na | na | na | 69 | 69 | 67 | 67 | na | na | na | na | na | na | na | na | na | na | na | na | na | na | mA
 |  | x16 | na | 55 | na | 51 | na | 49 | 48 | 46 | na | na | na | 55 | na | 51 | na | 49 | 48 | 46 | na | na | na | 34 | na | 73 | na | 32 | na | na | na | na | na | na | 69 | 69 | 67 | 67 | na | na | na | na | na | na | 85 | 85 | 83 | 83 | na | na | na | na | mA
IDD2P (Slow) | Maximum precharge power-down standby current(Slow Exit) | x4/x8 | na | 12 | na | 12 | na | 12 | 12 | 12 | na | na | na | 12 | na | 12 | na | 12 | 12 | 12 | na | na | na | 12 | na | 18 | na | 10 | na | na | na | na | na | na | 11 | 11 | 11 | 11 | na | na | na | na | na | na | na | na | na | na | na | na | na | na | mA
 |  | x16 | na | 12 | na | 12 | na | 12 | 12 | 12 | na | na | na | 12 | na | 12 | na | 12 | 12 | 12 | na | na | na | 12 | na | 18 | na | 12 | na | na | na | na | na | na | 11 | 11 | 11 | 11 | na | na | na | na | na | na | 22 | 22 | 22 | 22 | na | na | na | na | mA
IDD2P (Fast) | Maximum precharge power-down standby current(Fast Exit) | x4/x8 | na | 15 | na | 15 | na | 15 | 15 | 15 | na | na | na | 15 | na | 15 | na | 15 | 15 | 15 | na | na | na | 13 | na | 37 | na | 11 | na | na | na | na | na | na | 16 | 16 | 14 | 14 | na | na | na | na | na | na | na | na | na | na | na | na | na | na | mA
 |  | x16 | na | 15 | na | 15 | na | 15 | 15 | 15 | na | na | na | 15 | na | 15 | na | 15 | 15 | 15 | na | na | na | 14 | na | 37 | na | 12 | na | na | na | na | na | na | 16 | 16 | 14 | 14 | na | na | na | na | na | na | 27 | 27 | 25 | 25 | na | na | na | na | mA
IDD2N | Maximum precharge standby current | x4/x8 | na | 23 | na | 23 | na | 23 | 23 | 23 | na | na | na | 23 | na | 23 | na | 23 | 23 | 23 | na | na | na | 22 | na | 35 | na | 16 | na | na | na | na | na | na | 38 | 38 | 36 | 36 | na | na | na | na | na | na | na | na | na | na | na | na | na | na | mA
 |  | x16 | na | 23 | na | 23 | na | 23 | 23 | 23 | na | na | na | 23 | na | 23 | na | 23 | 23 | 23 | na | na | na | 22 | na | 35 | na | 17 | na | na | na | na | na | na | 38 | 38 | 36 | 36 | na | na | na | na | na | na | 49 | 49 | 47 | 47 | na | na | na | na | mA
IDD3P | Maximum active power-down standby current | x4/x8 | na | 17 | na | 17 | na | 17 | 17 | 17 | na | na | na | 22 | na | 22 | na | 22 | 22 | 22 | na | na | na | 17 | na | 41 | na | 15 | na | na | na | na | na | na | 38 | 38 | 36 | 36 | na | na | na | na | na | na | na | na | na | na | na | na | na | na | mA
 |  | x16 | na | 17 | na | 17 | na | 17 | 17 | 17 | na | na | na | 22 | na | 22 | na | 22 | 22 | 22 | na | na | na | 19 | na | 41 | na | 17 | na | na | na | na | na | na | 38 | 38 | 36 | 36 | na | na | na | na | na | na | 49 | 49 | 47 | 47 | na | na | na | na | mA
IDD3N | Maximum active standby current | x4/x8 | na | 40 | na | 37 | na | 35 | 33 | 31 | na | na | na | 40 | na | 37 | na | 35 | 33 | 31 | na | na | na | 23 | na | 41 | na | 20 | na | na | na | na | na | na | 53 | 53 | 51 | 51 | na | na | na | na | na | na | na | na | na | na | na | na | na | na | mA
 |  | x16 | na | 43 | na | 38 | na | 37 | 36 | 33 | na | na | na | 43 | na | 39 | na | 37 | 36 | 33 | na | na | na | 25 | na | 49 | na | 22 | na | na | na | na | na | na | 53 | 53 | 51 | 51 | na | na | na | na | na | na | 64 | 64 | 62 | 62 | na | na | na | na | mA
IDD4R | Maximum read burst current | x4 | na | 125 | na | 110 | na | 100 | 88 | 74 | na | na | na | 120 | na | 106 | na | 96 | 84 | 70 | na | na | na | 110 | na | 164 | na | 90 | na | na | na | na | na | na | 135 | 135 | 125 | 125 | na | na | na | na | na | na | na | na | na | na | na | na | na | na | mA
 |  | x8 | na | 125 | na | 110 | na | 100 | 88 | 74 | na | na | na | 125 | na | 110 | na | 100 | 88 | 74 | na | na | na | 110 | na | 174 | na | 90 | na | na | na | na | na | na | 135 | 135 | 125 | 125 | na | na | na | na | na | na | na | na | na | na | na | na | na | na | mA
 |  | x16 | na | 180 | na | 155 | na | 135 | 115 | 95 | na | na | na | 180 | na | 155 | na | 135 | 115 | 95 | na | na | na | 130 | na | 252 | na | 110 | na | na | na | na | na | na | 195 | 195 | 185 | 185 | na | na | na | na | na | na | 211 | 211 | 201 | 201 | na | na | na | na | mA
IDD4W | Maximum write burst current | x4 | na | 126 | na | 114 | na | 103 | 91 | 79 | na | na | na | 122 | na | 110 | na | 99 | 87 | 75 | na | na | na | 110 | na | 133 | na | 90 | na | na | na | na | na | na | 135 | 135 | 125 | 125 | na | na | na | na | na | na | na | na | na | na | na | na | na | na | mA
 |  | x8 | na | 126 | na | 114 | na | 103 | 91 | 79 | na | na | na | 126 | na | 114 | na | 103 | 91 | 79 | na | na | na | 110 | na | 141 | na | 90 | na | na | na | na | na | na | 135 | 135 | 125 | 125 | na | na | na | na | na | na | na | na | na | na | na | na | na | na | mA
 |  | x16 | na | 184 | na | 164 | na | 146 | 127 | 107 | na | na | na | 184 | na | 164 | na | 146 | 127 | 107 | na | na | na | 140 | na | 190 | na | 120 | na | na | na | na | na | na | 195 | 195 | 185 | 185 | na | na | na | na | na | na | 211 | 211 | 201 | 201 | na | na | na | na | mA
IDD5B | Maximum burst refresh current | x4/x8 | na | 170 | na | 165 | na | 160 | 160 | 155 | na | na | na | 190 | na | 184 | na | 182 | 181 | 179 | na | na | na | 160 | na | 242 | na | 152 | na | na | na | na | na | na | 250 | 250 | 245 | 245 | na | na | na | na | na | na | na | na | na | na | na | na | na | na | mA
 |  | x16 | na | 170 | na | 165 | na | 160 | 160 | 155 | na | na | na | 190 | na | 184 | na | 182 | 181 | 179 | na | na | na | 160 | na | 242 | na | 156 | na | na | na | na | na | na | 250 | 250 | 245 | 245 | na | na | na | na | na | na | 261 | 261 | 256 | 256 | na | na | na | na | mA
 | tCK used for current measurements (see current notes) |  | 0.938 | 0.938 | 1.07 | 1.07 | 1.25 | 1.25 | 1.5 | 1.875 | 1.875 | 2.5 | 0.938 | 0.938 | 1.07 | 1.07 | 1.25 | 1.25 | 1.5 | 1.875 | 1.875 | 2.5 | 0.938 | 0.938 | 1.07 | 1.07 | 1.25 | 1.25 | 1.5 | 1.875 | 1.875 | 2.5 | 0.938 | 0.938 | 1.07 | 1.07 | 1.25 | 1.25 | 1.5 | 1.875 | 1.875 | 2.5 | 0.938 | 0.938 | 1.07 | 1.07 | 1.25 | 1.25 | 1.5 | 1.875 | 1.875 | 2.5 | ns
tRRD | Minimum activate-to-activate timing (different bank) | x4/x8 | 6 | 6 | 6 | 6 | 6 | 6 | 6 | 7.5 | 7.5 | 10 | 6 | 6 | 6 | 6 | 6 | 6 | 6 | 7.5 | 7.5 | 10 | 6 | 6 | 6 | 5 | 6 | 6 | 6 | 7.5 | 7.5 | 10 | 6 | 6 | 6 | 6 | 6 | 6 | 6 | 7.5 | 7.5 | 10 | 6 | 6 | 6 | 6 | 6 | 6 | 6 | 7.5 | 7.5 | 10 | ns
 |  | x16 | 7.5 | 7.5 | 7.5 | 7.5 | 7.5 | 7.5 | 7.5 | 10 | 10 | 10 | 7.5 | 7.5 | 7.5 | 7.5 | 7.5 | 7.5 | 7.5 | 10 | 10 | 10 | 7.5 | 7.5 | 7.5 | 6 | 7.5 | 7.5 | 7.5 | 10 | 10 | 10 | 7.5 | 7.5 | 7.5 | 7.5 | 7.5 | 7.5 | 7.5 | 10 | 10 | 10 | 7.5 | 7.5 | 7.5 | 7.5 | 7.5 | 7.5 | 7.5 | 10 | 10 | 10 | ns
tRC | Minimum activate-to-activate timing (same bank) |  | 45.155 | 46.09 | 46.84 | 47.91 | 47.5 | 48.75 | 49.5 | 50.625 | 52.5 | 52.5 | 45.155 | 46.09 | 46.84 | 47.91 | 47.5 | 48.75 | 49.5 | 50.625 | 52.5 | 52.5 | 45.155 | 46.09 | 46.09 | 45 | 47.5 | 48.75 | 49.5 | 50.625 | 52.5 | 52.5 | 45.155 | 46.09 | 46.84 | 47.91 | 47.5 | 48.75 | 49.5 | 50.625 | 52.5 | 52.5 | 45.155 | 46.09 | 46.84 | 47.91 | 47.5 | 48.75 | 49.5 | 50.625 | 52.5 | 52.5 | ns
tRAS | tRAS used for IDD0 calculation |  | 36 | 36 | 34 | 34 | 35 | 35 | 36 | 37.5 | 37.5 | 37.5 | 36 | 36 | 34 | 34 | 35 | 35 | 36 | 37.5 | 37.5 | 37.5 | 36 | 36 | 36 | 32 | 35 | 35 | 36 | 37.5 | 37.5 | 37.5 | 36 | 36 | 34 | 34 | 35 | 35 | 36 | 37.5 | 37.5 | 37.5 | 36 | 36 | 34 | 34 | 35 | 35 | 36 | 37.5 | 37.5 | 37.5 | ns
tRFC (MIN) | Minimum refresh-to-refresh cycle time |  | 110 | 110 | 110 | 110 | 110 | 110 | 110 | 110 | 110 | 110 | 160 | 160 | 160 | 160 | 160 | 160 | 160 | 160 | 160 | 160 | 260 | 260 | 260 | 243 | 260 | 260 | 260 | 260 | 260 | 260 | 350 | 350 | 350 | 350 | 350 | 350 | 350 | 350 | 350 | 350 | 350 | 350 | 350 | 350 | 350 | 350 | 350 | 350 | 350 | 350 | ns
tREFI | Average periodic refresh cycle time |  | 7.8 | 7.8 | 7.8 | 7.8 | 7.8 | 7.8 | 7.8 | 7.8 | 7.8 | 7.8 | 7.8 | 7.8 | 7.8 | 7.8 | 7.8 | 7.8 | 7.8 | 7.8 | 7.8 | 7.8 | 7.8 | 7.8 | 7.8 | 7.8 | 7.8 | 7.8 | 7.8 | 7.8 | 7.8 | 7.8 | 7.8 | 7.8 | 7.8 | 7.8 | 7.8 | 7.8 | 7.8 | 7.8 | 7.8 | 7.8 | 7.8 | 7.8 | 7.8 | 7.8 | 7.8 | 7.8 | 7.8 | 7.8 | 7.8 | 7.8 | µs
tCK (MIN) | Minimum tCK cycle rate |  | 0.938 | 0.938 | 1.07 | 1.07 | 1.25 | 1.25 | 1.5 | 1.875 | 1.875 | 2.5 | 0.938 | 0.938 | 1.07 | 1.07 | 1.25 | 1.25 | 1.5 | 1.875 | 1.875 | 2.5 | 0.938 | 0.938 | 1.07 | 1.07 | 1.25 | 1.25 | 1.5 | 1.875 | 1.875 | 2.5 | 0.938 | 0.938 | 1.07 | 1.07 | 1.25 | 1.25 | 1.5 | 1.875 | 1.875 | 2.5 | 0.938 | 0.938 | 1.07 | 1.07 | 1.25 | 1.25 | 1.5 | 1.875 | 1.875 | 2.5 | ns
tCK (MAX) | Maximum tCK cycle rate |  | 3.3 | 3.3 | 3.3 | 3.3 | 3.3 | 3.3 | 3.3 | 3.3 | 3.3 | 3.3 | 3.3 | 3.3 | 3.3 | 3.3 | 3.3 | 3.3 | 3.3 | 3.3 | 3.3 | 3.3 | 3.3 | 3.3 | 3.3 | 3.3 | 3.3 | 3.3 | 3.3 | 3.3 | 3.3 | 3.3 | 3.3 | 3.3 | 3.3 | 3.3 | 3.3 | 3.3 | 3.3 | 3.3 | 3.3 | 3.3 | 3.3 | 3.3 | 3.3 | 3.3 | 3.3 | 3.3 | 3.3 | 3.3 | 3.3 | 3.3 | ns
Do Not Go Below This Box Do Not Go Below This Box Do Not Go Below This Box Do Not Go Below This Box Do Not Go Below This Box Do Not Go Below This Box Do Not Go Below This Box Do Not Go Below This Box

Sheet: DDR3 Config
DDR3L SDRAM Configuration
 | DRAM Density | 4Gb
 | Number of DQs per DRAM | 16
 | Speed Grade | -107
 | DDR3 or DDR3L
 | Mode Register bit 12: Precharge PD Exit Mode
Parameter | Condition | Value | Units
 | Maximum VCC | 1.435 | V
 | Minimum VCC | 1.283 | V
 | Number of DQ strobes (DQS) per DRAM | 4
 | Number of data mask (DM) per DRAM | 2
IDD0 | Maximum active precharge current | 73 | mA
IDD2P | Maximum precharge power-down standby current | 37 | mA
IDD2N | Maximum precharge standby current | 35 | mA
IDD3P | Maximum active power-down standby current | 41 | mA
IDD3N | Maximum active standby current | 49 | mA
IDD4R | Maximum read burst current | 252 | mA
IDD4W | Maximum write burst current | 190 | mA
IDD5A | Maximum burst refresh current | 242 | mA
 | tCK used for current measurements (see current notes) | 1.07 | ns
tRRD | Minimum activate-to-activate timing (different bank) | 6 | ns
tRC | Minimum activate-to-activate timing (same bank) | 45 | ns
tRAS | tRAS used for IDD0 calculation | 32 | ns
tRFC (MIN) | Minimum refresh-to-refresh cycle time | 243 | ns
tREFI | Average periodic refresh cycle time | 7.8 | µs
tCK (MIN) | Minimum tCK cycle rate | 1.07 | ns
tCK (MAX) | Maximum tCK cycle rate | 3.3 | ns

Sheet: System Config
 |  |  |  |  | READ I/O Power |  |  |  |  |  |  | WRITE I/O Power
 | DRAM Usage Conditions in the System Environment
 | System VDD | 1.35 | V
 | System CK frequency | 900 | MHz
 | Burst length | 8 |  | must be either 4 or 8
PdqRD | DDR3 SDRAM output power per individual DQ on this DRAM during READs from this DRAM | 4.4 | mW | This value is the DRAM I/O power plus module series resistor power per DQ. The calculator to the right will estimate and populate the entries to the left
PdqWR | DDR3 SDRAM termination power per individual DQ during WRITEs to this DRAM | 16.7 | mW |  |  | Enter values in dark green boxes below |  |  |  |  |  |  | Enter values in dark green boxes below
PdqRDoth | DDR3 SDRAM termination power per individual DQ during READs from other DRAM | 24.0 | mW | This value is the termination power plus module series resistor power per DQ. The calculator to the right will estimate and populate the entries to the left |  | RTTuC= | 120 | Rz1= | 34 | RTTu2= | 40 |  | RzC= | 34 | RTTu1= | 60 | RTTu2= | 40
PdqWRoth | DDR3 SDRAM termination power per individual DQ during WRITEs to other DRAM | 24.3 | mW |  |  | RTTdC= | 120 | Rs1= | 15 | RTTd2= | 40 |  |  |  | RTTd1= | 60 | RTTd2= | 40
 |  |  |  |  |  | VDDq= | 1.350 |  |  | Rs2= | 15 |  | VDDq= | 1.350 | Rs1= | 4 | Rs2= | 15
BNK_PRE% | The percentage of time that all banks on the DRAM are in a precharged state | 25% |  |  |  | Calculated values in light green boxes below |  |  |  |  |  |  | Calculated values in light green boxes below
CKE_LO_PRE% | The percentage of the all bank precharge time for which CKE is held LOW | 25% |  |  |  | N3= (mV) | 465.1554404 | N1= (mV) | 322.7609178 | N2= (mV) | 547.549963 |  | N3= (mV) | 447.8365385 | N1= (mV) | 474.5616516 | N2= (mV) | 545.1923077
CKE_LO_ACT% | The percentage of the at least one bank active time for which CKE is held LOW | 25% |  |  |  | RTTC = (mW) | 8.3 | Rz = (mW) | 3.1 | RTTd2 = (mW) | 23.6 |  | Rz = (mW) | 5.9 | RTTd1 = (mW) | 16.5 | RTTd2 = (mW) | 23.6
 |  |  |  |  |  |  |  | Rs1 = (mW) | 1.4 | Rs2= (mW) | 0.45 |  |  |  | Rs1= (mW) | 0.18 | Rs2= (mW) | 0.6
PH% | Page hit rate | 50%
RDsch% | The percentage of clock cycles which are outputting read data from the DRAM | 30%
WRsch% | The percentage of clock cycles which are inputting write data to the DRAM | 30%
 |  | 50% |  | ratio of reads to writes
termRDsch% | The percentage of clock cycles which are terminating read data to another DRAM | 0% |  | must be 0% for a 1-rank system
termWRsch% | The percentage of clock cycles which are terminating write data to another DRAM | 0% |  | must be 0% for a 1-rank system
tRRDsch | The average time between ACT commands to this DRAM (includes ACT to same or different banks in the same DRAM device) | 14.8 | ns
 |  |  |  | The above is calculated from page hit rate read/write bus utilization. No entry is necessary.
 | Values that may be updated are shown in green. This will be dependent on how the system accesses the DRAM.
 | Calculated values in light green.

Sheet: Power Calcs
System Derating for 4Gb DDR3L SDRAM (x16, -107 Speed Grade)
Power is calculated based upon data sheet test conditions and maximum limits, scaled for used conditions an actual VDD. and finally scaled for the frequency being used. All parameters are calculated and require no user input.
 | Power Based on Data Sheet Test Conditions and Maximum Limits |  |  | Power Derated for System Usage Conditions Input into This Model |  |  | Power Scaled for Actual System Conditions (DRAM Usage, CK Frequency, and VCC)
Background power used during precharge power-down | Pds(PRE_PDN) | 53.1 | mW | Psch(PRE_PDN) | 3.3 | mW | Psys(PRE_PDN) | 2.8 | mW
Background power used during idle standby | Pds(PRE_STBY) | 50.2 | mW | Psch(PRE_STBY) | 9.4 | mW | Psys(PRE_STBY) | 8.0 | mW
Background power used during active power-down | Pds(ACT_PDN) | 58.8 | mW | Psch(ACT_PDN) | 11.0 | mW | Psys(ACT_PDN) | 9.4 | mW
Background power used during active standby | Pds(ACT_STBY) | 70.3 | mW | Psch(ACT_STBY) | 39.6 | mW | Psys(ACT_STBY) | 33.7 | mW
Background power to complete refreshes | Pds(REF) | 8.6 | mW | Psch(REF) | 8.6 | mW | Psys(REF) | 7.6 | mW
DRAM power for ACT/PRE commands | Pds(ACT) | 40.2 | mW | Psch(ACT) | 122.4 | mW | Psys(ACT) | 108.3 | mW
DRAM write power | Pds(WR) | 202.3 | mW | Psch(WR) | 60.7 | mW | Psys(WR) | 51.7 | mW
DRAM read power | Pds(RD) | 291.3 | mW | Psch(RD) | 87.4 | mW | Psys(RD) | 74.5 | mW
DQ output power | Pds(DQ) | 88.3 | mW | Psch(DQ) | 26.5 | mW | Psys(DQ) | 26.5 | mW
Term power for writes | Pds(termW) | 367.5 | mW | Psch(termW) | 110.3 | mW | Psys(termW) | 110.3 | mW
Term power for reads from another rank | Pds(termRoth) | 480.9 | mW | Psch(termRoth) | 0.0 | mW | Psys(termRoth) | 0.0 | mW
Term power for writes from another rank | Pds(termWoth) | 533.6 | mW | Psch(termWoth) | 0.0 | mW | Psys(termWoth) | 0.0 | mW
 |  |  |  |  |  |  | Total DRAM Power Consumed | 432.9 | mW
 |  |  |  |  |  |  | 2nd rank DRAM Power Consumed | 0.0 | mW

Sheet: Summary
4Gb DDR3L SDRAM with 16 DQs and a -107 Speed Grade
 |  | System is operating at 900 MHz clock with VDD = 1.35V. Read bandwidth is 1080 MT/s with write bandwidth of 1080 MT/s. The DRAM terminates 0 MT/s. ACT commands are separated by 14.8ns on average. All parameters are calculated and require no user input.
 | Psys Power Consumption Summary
 | ACT |  | 108.3 | mW | ACT | 108.3
 |  | Total Activate Power | 108.3 | mW | RD | 74.5
 | RD |  | 74.5 | mW | WR | 51.7
 | WR |  | 51.7 | mW | READ I/O | 26.5
 | READ I/O |  | 26.5 | mW | Write ODT | 110.3
 | Write ODT |  | 110.3 | mW | ACT_STBY | 33.7
 |  | Total RD/WR/Term Power | 263.0 | mW | PRE_STBY | 8.0
 | ACT_STBY |  | 33.7 | mW | ACT_PDN | 9.4
 | PRE_STBY |  | 8.0 | mW | PRE_PDN | 2.8
 | ACT_PDN |  | 9.4 | mW | REF | 7.6
 | PRE_PDN |  | 2.8 | mW | TERM 2nd rank | 0.0
 | REF |  | 7.6 | mW
 |  | Total Background Power | 61.6 | mW
 | Total DDR3 SDRAM Power |  | 432.9 | mW
 | TERM 2nd rank |  | 0.0 | mW
 | Current Draw |  | 320.6 | mA
System is operating at 900 MHz clock with VDD = 1.35V.

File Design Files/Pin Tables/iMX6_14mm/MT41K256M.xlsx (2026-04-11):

Count | Pin | Name | Type | Mode | Alignment | X | Y
1 | K3 | ~{CAS} | Input | Line | Right | 0 | 1900
1 | K7 | ~{CK} | Input | Line | Right | 0 | 1300
1 | L2 | ~{CS} | Input | Line | Right | 0 | 1500
1 | G3 | ~{LDQS} | Input | Line | Left | 2500 | 2200
1 | J3 | ~{RAS} | Input | Line | Right | 0 | 1700
1 | T2 | ~{RESET} | Input | Line | Right | 0 | 800
1 | B7 | ~{UDQS} | Input | Line | Left | 2500 | 2500
1 | L3 | ~{WE} | Input | Line | Right | 0 | 2100
1 | N3 | A0 | Input | Line | Right | 0 | 2500
1 | P7 | A1 | Input | Line | Right | 0 | 2600
1 | L7 | A10/AP | Input | Line | Right | 0 | 3500
1 | R7 | A11 | Input | Line | Right | 0 | 3600
1 | N7 | A12/~{BC} | Input | Line | Right | 0 | 3700
1 | T3 | A13 | Input | Line | Right | 0 | 3800
1 | T7 | A14 | Input | Line | Right | 0 | 3900
1 | P3 | A2 | Input | Line | Right | 0 | 2700
1 | N2 | A3 | Input | Line | Right | 0 | 2800
1 | P8 | A4 | Input | Line | Right | 0 | 2900
1 | P2 | A5 | Input | Line | Right | 0 | 3000
1 | R8 | A6 | Input | Line | Right | 0 | 3100
1 | R2 | A7 | Input | Line | Right | 0 | 3200
1 | T8 | A8 | Input | Line | Right | 0 | 3300
1 | R3 | A9 | Input | Line | Right | 0 | 3400
1 | M2 | BA0 | Input | Line | Right | 0 | 4100
1 | N8 | BA1 | Input | Line | Right | 0 | 4200
1 | M3 | BA2 | Input | Line | Right | 0 | 4300
1 | J7 | CK | Input | Line | Right | 0 | 1200
1 | K9 | CKE | Input | Line | Right | 0 | 1000
1 | E3 | DQ0 | Input | Line | Left | 2500 | 400
1 | F7 | DQ1 | Input | Line | Left | 2500 | 500
1 | C8 | DQ10 | Input | Line | Left | 2500 | 1400
1 | C2 | DQ11 | Input | Line | Left | 2500 | 1500
1 | A7 | DQ12 | Input | Line | Left | 2500 | 1600
1 | A2 | DQ13 | Input | Line | Left | 2500 | 1700
1 | B8 | DQ14 | Input | Line | Left | 2500 | 1800
1 | A3 | DQ15 | Input | Line | Left | 2500 | 1900
1 | F2 | DQ2 | Input | Line | Left | 2500 | 600
1 | F8 | DQ3 | Input | Line | Left | 2500 | 700
1 | H3 | DQ4 | Input | Line | Left | 2500 | 800
1 | H8 | DQ5 | Input | Line | Left | 2500 | 900
1 | G2 | DQ6 | Input | Line | Left | 2500 | 1000
1 | H7 | DQ7 | Input | Line | Left | 2500 | 1100
1 | D7 | DQ8 | Input | Line | Left | 2500 | 1200
1 | C3 | DQ9 | Input | Line | Left | 2500 | 1300
1 | E7 | LDM | Input | Line | Left | 2500 | 2700
1 | F3 | LDQS | Input | Line | Left | 2500 | 3000
1 | J1 | NC | Input | Line | Left | 2500 | 3100
1 | J9 | NC | Input | Line | Left | 2500 | 3200
1 | L1 | NC | Input | Line | Left | 2500 | 3300
1 | L9 | NC | Input | Line | Left | 2500 | 3400
1 | M7 | NC | Input | Line | Left | 2500 | 3500
1 | K1 | ODT | Input | Line | Right | 0 | 400
1 | D3 | UDM | Input | Line | Left | 2500 | 2800
1 | C7 | UDQS | Input | Line | Left | 2500 | 2400
1 | B2 | VDD | Power input | Line | Down | 400 | 300
1 | D9 | VDD | Power input | Line | Down | 500 | 300
1 | G7 | VDD | Power input | Line | Down | 600 | 300
1 | K2 | VDD | Power input | Line | Down | 700 | 300
1 | K8 | VDD | Power input | Line | Down | 800 | 300
1 | N1 | VDD | Power input | Line | Down | 900 | 300
1 | N9 | VDD | Power input | Line | Down | 1000 | 300
1 | R1 | VDD | Power input | Line | Down | 1100 | 300
1 | R9 | VDD | Power input | Line | Down | 1200 | 300
1 | A1 | VDDQ | Power input | Line | Down | 1300 | 300
1 | A8 | VDDQ | Power input | Line | Down | 1400 | 300
1 | C1 | VDDQ | Power input | Line | Down | 1500 | 300
1 | C9 | VDDQ | Power input | Line | Down | 1600 | 300
1 | D2 | VDDQ | Power input | Line | Down | 1700 | 300
1 | E9 | VDDQ | Power input | Line | Down | 1800 | 300
1 | F1 | VDDQ | Power input | Line | Down | 1900 | 300
1 | H2 | VDDQ | Power input | Line | Down | 2000 | 300
1 | H9 | VDDQ | Power input | Line | Down | 2100 | 300
1 | M8 | VREFCA | Power input | Line | Right | 0 | 4600
1 | H1 | VREFDQ | Power input | Line | Right | 0 | 4800
1 | A9 | VSS | Power input | Line | Up | 400 | 4500
1 | B3 | VSS | Power input | Line | Up | 500 | 4500
1 | E1 | VSS | Power input | Line | Up | 600 | 4500
1 | G8 | VSS | Power input | Line | Up | 700 | 4500
1 | J2 | VSS | Power input | Line | Up | 800 | 4500
1 | J8 | VSS | Power input | Line | Up | 900 | 4500
1 | M1 | VSS | Power input | Line | Up | 1000 | 4500
1 | M9 | VSS | Power input | Line | Up | 1100 | 4500
1 | P9 | VSS | Power input | Line | Up | 1200 | 4500
1 | T1 | VSS | Power input | Line | Up | 1300 | 4500
1 | T9 | VSS | Power input | Line | Up | 1400 | 4500
1 | P1 | VSS | Power input | Line | Up | 1500 | 4500
1 | B1 | VSSQ | Power input | Line | Up | 1600 | 4500
1 | B9 | VSSQ | Power input | Line | Up | 1700 | 4500
1 | D1 | VSSQ | Power input | Line | Up | 1800 | 4500
1 | D8 | VSSQ | Power input | Line | Up | 1900 | 4500
1 | E2 | VSSQ | Power input | Line | Up | 2000 | 4500
1 | E8 | VSSQ | Power input | Line | Up | 2100 | 4500
1 | F9 | VSSQ | Power input | Line | Up | 2200 | 4500
1 | G1 | VSSQ | Power input | Line | Up | 2300 | 4500
1 | G9 | VSSQ | Power input | Line | Up | 2400 | 4500
1 | L8 | ZQ | Passive | Line | Right | 0 | 600

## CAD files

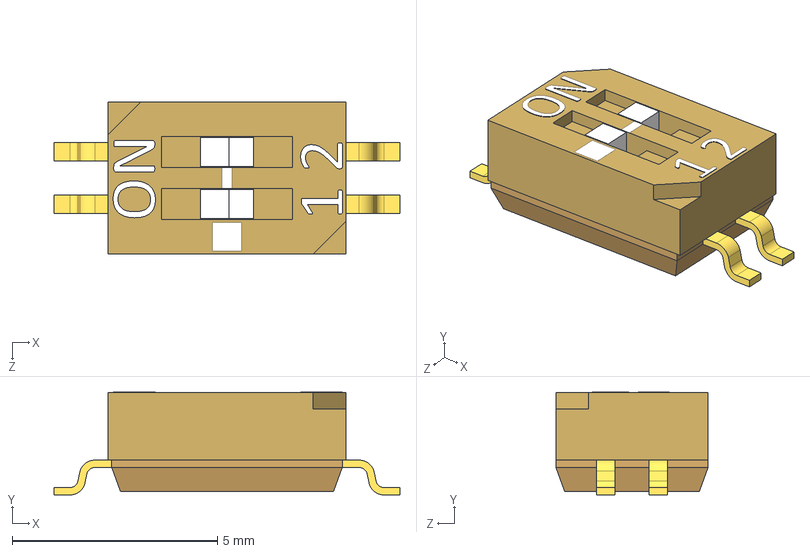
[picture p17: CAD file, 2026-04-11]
Kicad/3D Models/218-2.STEP
8.43 x 2.51 x 3.71 mm
218 terminal lead frame x 2

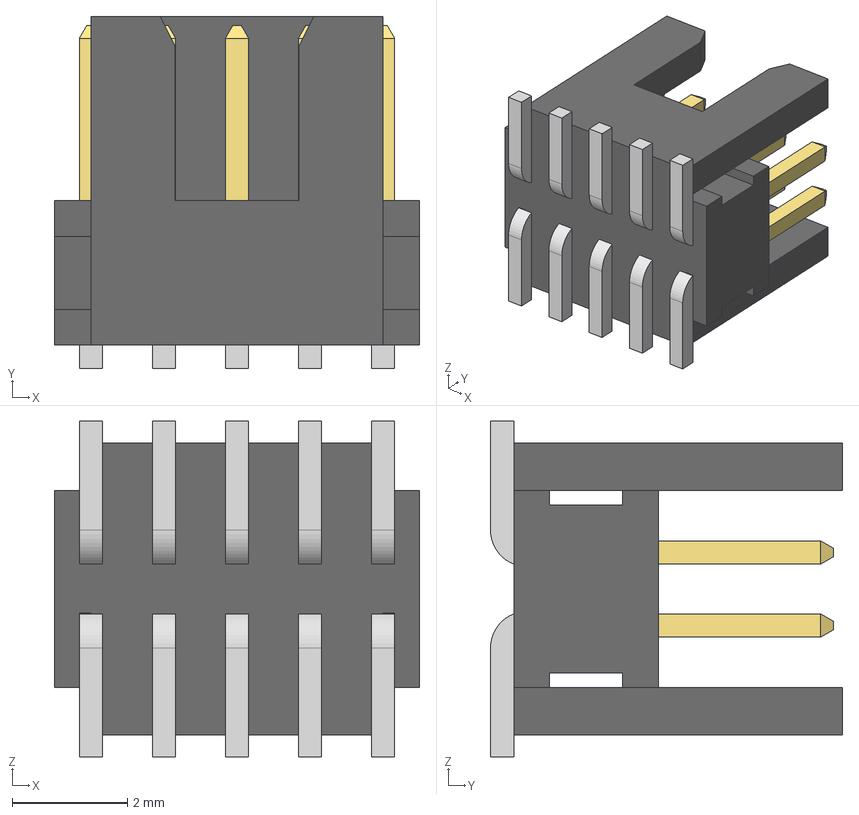
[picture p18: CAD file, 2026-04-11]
Kicad/3D Models/FTSH-105-XX-X-DV.step
6.35 x 6.12 x 5.84 mm
FTSH-105-01-L-DV-K_body
FTSH-105-01-L-DV-K_pins1
FTSH-105-01-L-DV-K_pins2

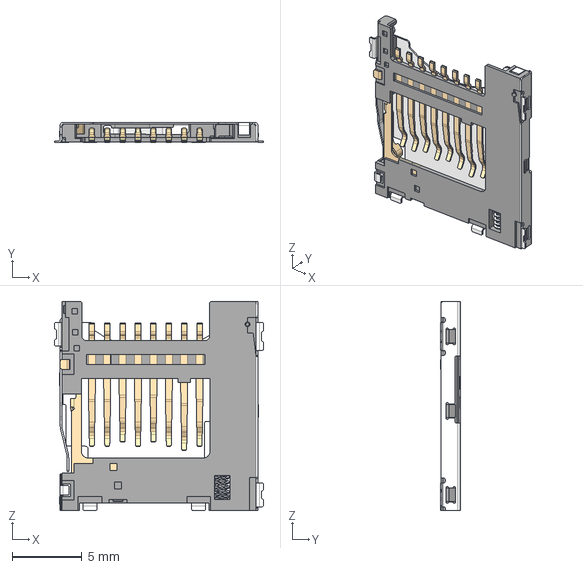
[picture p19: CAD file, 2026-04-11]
Kicad/3D Models/mem2090-00-145-00-a.stp
14.9 x 1.45 x 15.0 mm

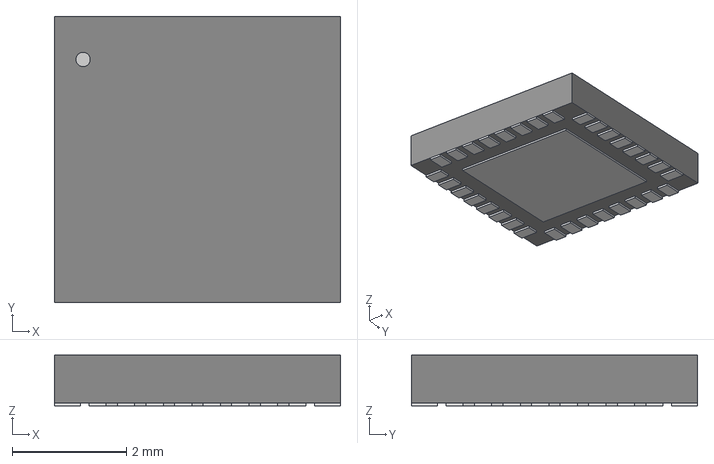
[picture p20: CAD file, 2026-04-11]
Kicad/3D Models/KSZ8081RNB_QFN-32_MCH.step
5.00 x 5.00 x 0.892 mm

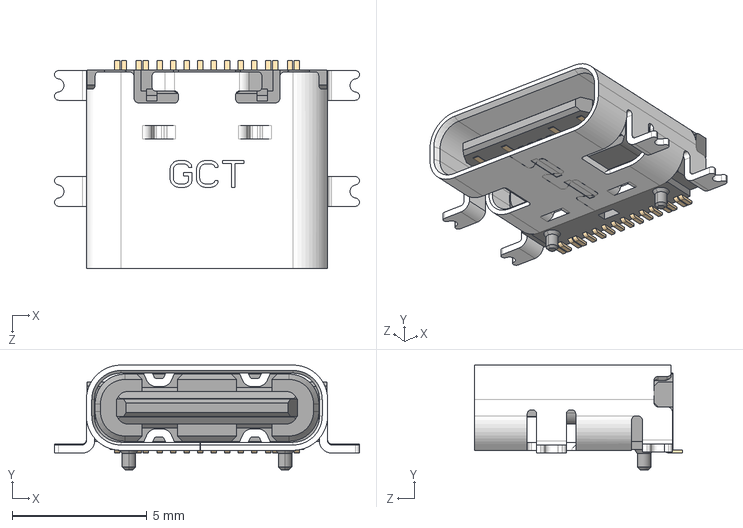
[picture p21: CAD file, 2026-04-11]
Kicad/3D Models/USB4110-GF-A--3DModel-STEP-269445.STEP
11.3 x 3.89 x 7.70 mm

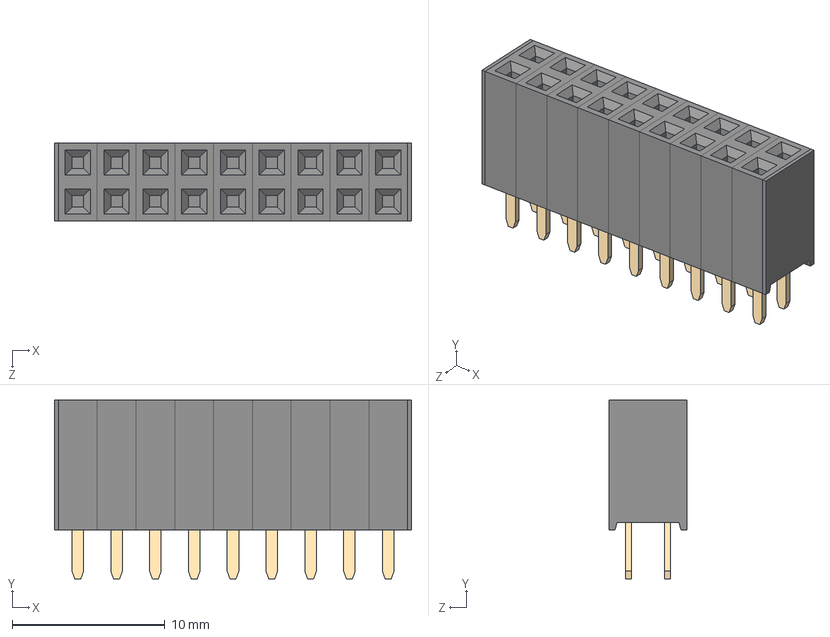
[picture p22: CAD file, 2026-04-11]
Kicad/3D Models/2x9header_PPPC092LFBN-RC.STEP
23.4 x 11.7 x 5.08 mm
NPPC202LFBN-RC_C09
Pin - Gold x 9

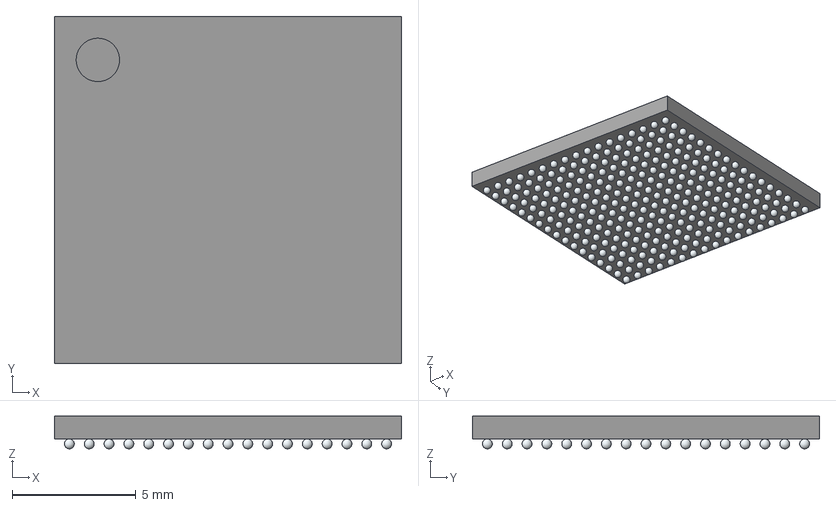
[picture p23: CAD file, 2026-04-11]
Kicad/3D Models/MCIMX6Y2DVM09AB.stp
14.0 x 14.0 x 1.32 mm

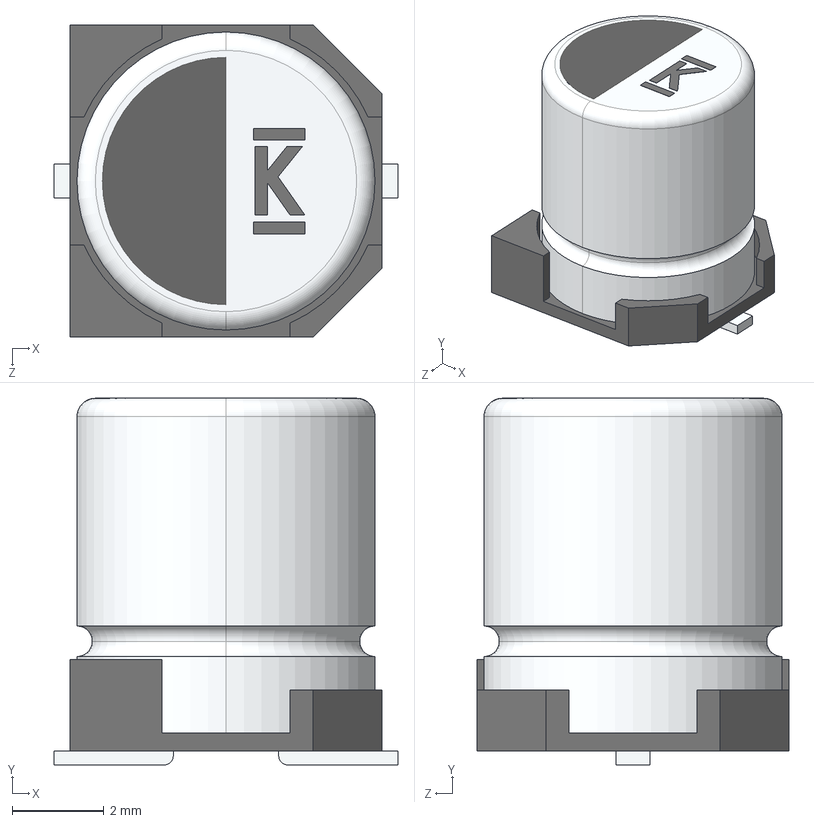
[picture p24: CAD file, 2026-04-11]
Kicad/3D Models/EEV107M035S9HAA.step
7.50 x 8.01 x 6.80 mm

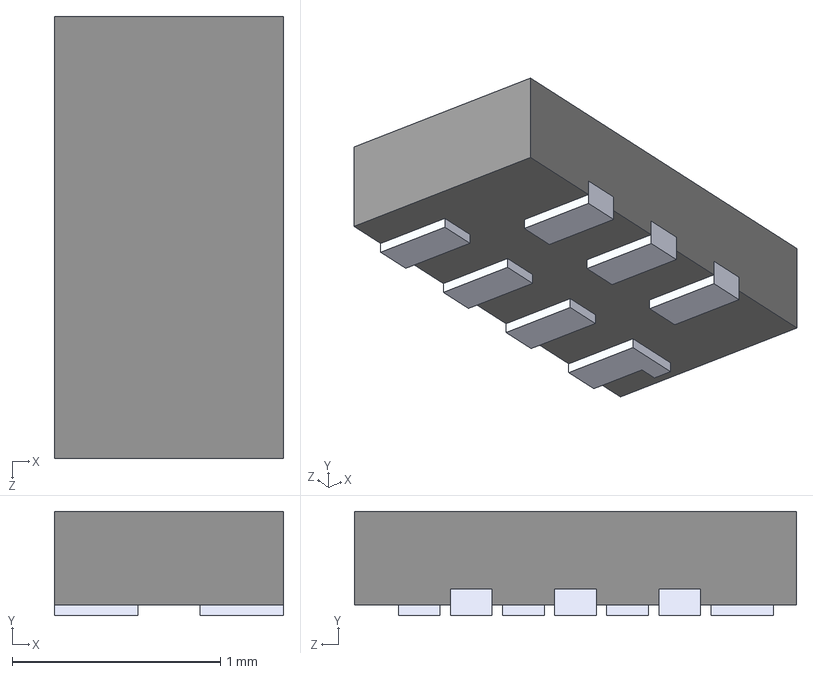
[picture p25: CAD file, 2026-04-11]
Kicad/3D Models/PUSB3AB6Z_ESD-SD.STEP
1.10 x 0.5 x 2.12 mm

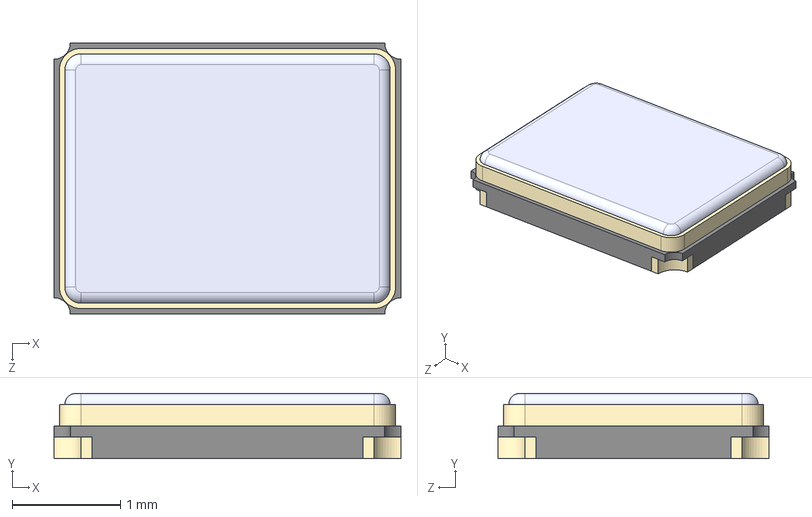
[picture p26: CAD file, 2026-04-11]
Kicad/3D Models/TSX-322524.0000MF15X-AC3.step
3.20 x 0.6 x 2.50 mm

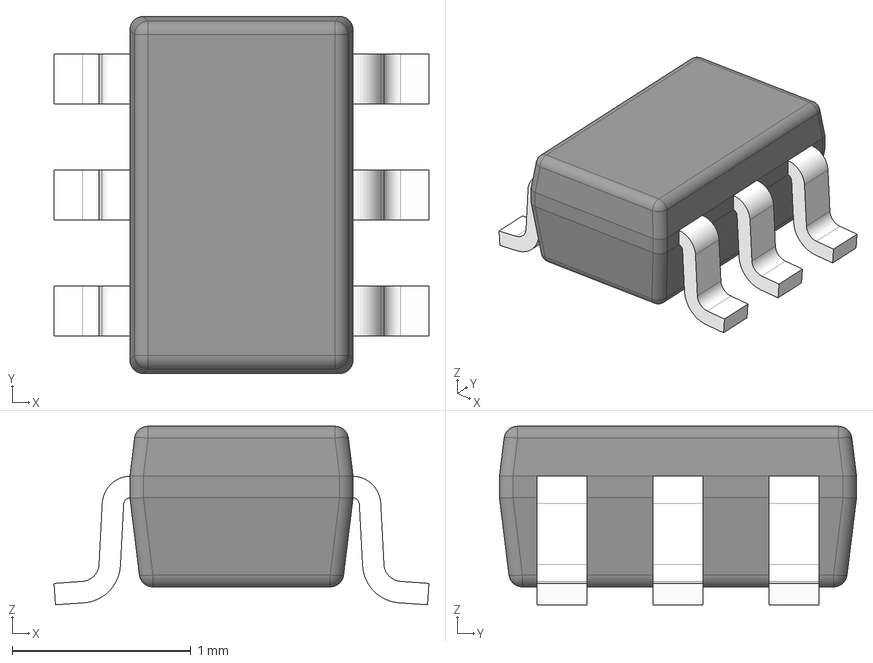
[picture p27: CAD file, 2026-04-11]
Kicad/3D Models/SN74LVC2G34_DCK0006A.stp
2.10 x 2.00 x 1.00 mm
BODY-SOT
LEAD-SOT x 6
PIN1-ID

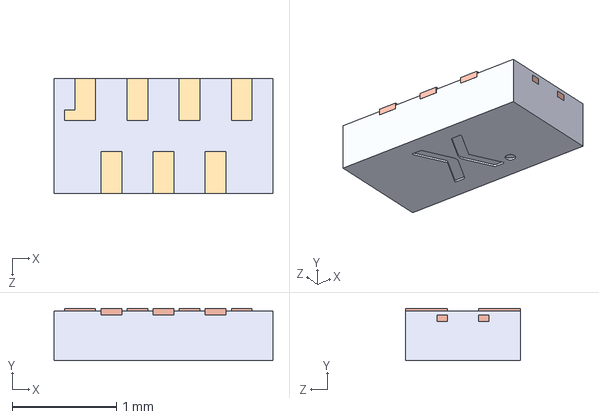
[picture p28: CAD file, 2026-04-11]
Kicad/3D Models/TLV773_LDO_SOT1358-1.step
2.10 x 0.5 x 1.10 mm
SOT1358-1 LF
SOT1358-1 Mold body

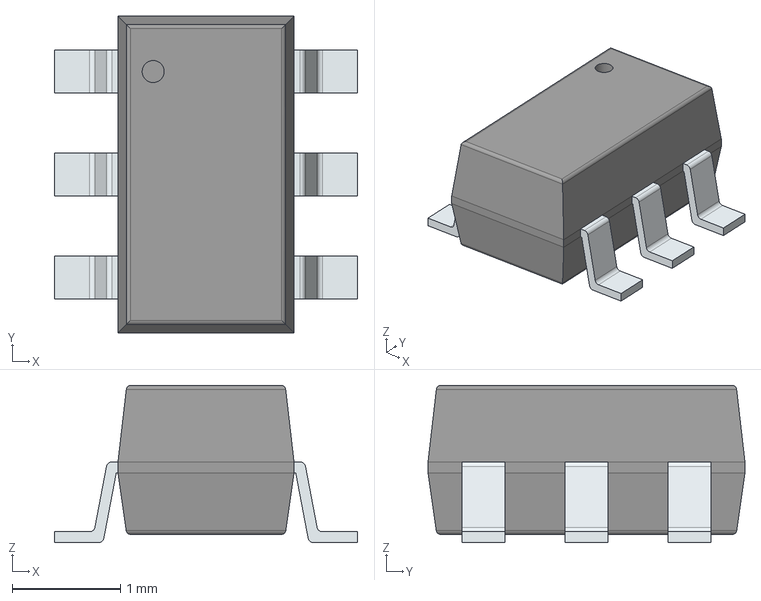
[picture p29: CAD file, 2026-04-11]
Kicad/3D Models/USBLC6-2SC6.stp
2.80 x 2.92 x 1.45 mm
PinsArrayLR

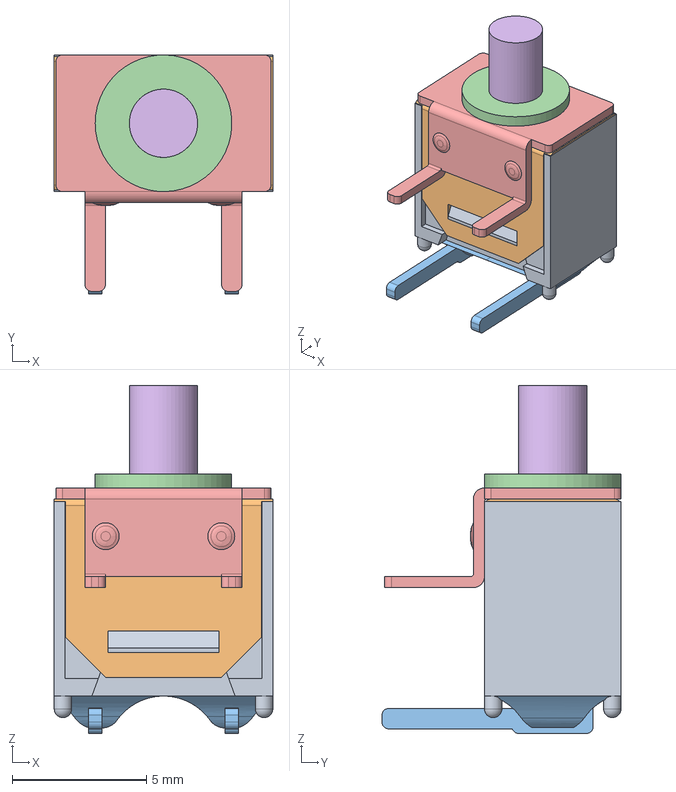
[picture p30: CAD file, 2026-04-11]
Kicad/3D Models/141_800SP9B10M6xE.stp
8.13 x 8.89 x 12.9 mm

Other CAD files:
Kicad/3D Models/SOT583_MP2182_MNP.step
Kicad/3D Models/P3V3_ind_74438322010.stp
Kicad/3D Models/5015.step
Kicad/3D Models/TPS3808E.stp
Kicad/3D Models/218-4.STEP
Kicad/3D Models/7499010121A (rev1).stp
Kicad/3D Models/AP3401KTTR-G1.stp
Kicad/3D Models/APX803S-29SR-7.stp
Kicad/3D Models/CP2102N-A02-GQFN20--3DModel-STEP-269445.STEP
Kicad/3D Models/DLW43SH510XK2K--3DModel-STEP-1.STEP
Kicad/3D Models/DRL0006A_buck.stp
Kicad/3D Models/DualAnd_74LVC2G08GT_115.step
Kicad/3D Models/DualNPN_MBT3904DW1T3G.stp
Kicad/3D Models/FC-135_32.7680KA-K0.stp
Kicad/3D Models/FTSH-105-01-L-DV-K.stp
Kicad/3D Models/Kingbright_dualLED.step
Kicad/3D Models/LevelShift_DCU0008A.stp
Kicad/3D Models/MIC2025_MSOP-8_MM_MCH.step
Kicad/3D Models/MT41K256M16TW-107_P.step
Kicad/3D Models/NCP380HMU05AATBG_LoadSwitch.stp
Kicad/3D Models/NX20P5090UK_awolfe.stp
Kicad/3D Models/PPPC042LFBN-RC.STEP
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

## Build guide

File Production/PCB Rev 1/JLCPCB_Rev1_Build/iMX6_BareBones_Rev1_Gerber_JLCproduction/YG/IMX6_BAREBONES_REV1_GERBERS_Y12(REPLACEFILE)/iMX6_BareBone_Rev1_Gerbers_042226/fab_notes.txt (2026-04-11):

NOTES: UNLESS OTHERWISE SPECIFIED.

1. FABRICATE PER IPC-6012A CLASS 2.
2. FOR BOARD THICKNESS AND IMPEDANCE DETAILS REFER STACKUP DOCUMENT.
3. PRINTED WIRING BOARD SHALL COMPLY WITH REQUIREMENTS OF ANSI/J-STD-003.
4. SURFACE FINISH: ENIG
5. SOLDERMASK ON BOTH SIDES OF THE BOARD SHALL BE LPI, COLOR GREEN.
6. SILK SCREEN LEGEND TO BE APPLIED PER LAYER STACKUP USING WHITE NON-CONDUCTIVE EPOXY INK.
7. THIS PRINTED WIRING BOARD IS DESIGNED WITH A MINIMUM CONDUCTOR WIDTH AND SPACING OF 4 MIL & 4 MILS.
8. ALL VIAS ARE TENTED ON BOTH SIDES UNLESS SOLDERMASK OPENED IN GERBER.
9. ALL VIAS ON PAD SHOULD BE FILLED WITH NON CONDUCTIVE EPOXY AND SURFACE SHOULD BE FLAT. FLATNESS TOLERANCE FOR VIA ON PADS: +0.000 /- 0.001 INCHES ON BOTH SIDES. THE MANUFACTURER IS REQUESTED TO SIZE PER THEIR SOLDERMASK TOLERANCE.
10. SOLDER MASK OPENING IS KEPT SAME SIZE AS PAD (1:1) FOR ALL COMPONENTS
11. MANUFACTURER'S IDENTIFICATION, DATECODE LETTER SHALL BE SILKSCREENED ON SOLDER SIDE OF THE BOARD.
12. TRACE WIDTH SHOULD BE ACCURATELY ETCHED. MAX TOLERANCE +/- 1 MIL
13. ALL DIMENSIONS ARE IN INCHES UNLESS OTHERWISE SPECIFIED.
14. FLATNESS REQUIREMENTS:
	A. BOW AND TWIST OF ASSEMBLY SUB-PANEL OR SINGULATED PWB SHALL NOT EXCEED 0.7% OF LONGEST SIDE
	B. TEST IN ACCORDANCE WITH THE CURRENT REVISION OF IPC-TM-650 2.4.22
15. LAYER TO LAYER REGISTRATION SHALL BE WITHIN +/-2 MIL
16. IMPEDANCE CONTROL REQUIREMENTS (ALL TOLERANCES +/- 10%):
	A. ALL 5.62 MIL WIDE SINGLE-END TRACES ON LAYER 1 (F.Cu) and LAYER 6 (B.Cu) SHALL BE 50 OHMS.
	B. ALL 5.21 MIL WIDE/6.00 MIL SPACE PAIRS ON LAYER 1 (F.Cu) and LAYER 6 (B.Cu) SHALL BE 90 OHMS.
	C. ALL 4.30 MIL WIDE/7.00 MIL SPACE PAIRS ON LAYER 1 (F.Cu) and LAYER 6 (B.Cu) SHALL BE 100 OHMS.
	D. ANY ADJUSTMENTS OF LINE WIDTH, SPACING OR DIELECTRIC THICKNESS SHALL REQUIRE APPROVAL FROM ANDREW WOLFE.
	E. TEST COUPONS SHALL BE PLACED AS REQUIRED BY MANUFACTURER FOR IMPEDANCE MEASUREMENTS. 
	F. IMPEDANCE TEST RESULTS MUST BE APPROVED BY ANDREW WOLFE.
17. FINISHED PCB MUST BE PANELIZED FOR ASSEMBLY ACCORDING TO MANUFACTURER REQUIREMENTS.
    THE ADDITION OF RAILS AND NON-PLATED TOOLING HOLES ARE AT THE DISCRETION OF THE MANUFACTURER.
    PANELIZATION MUST BE APPROVED BY ANDREW WOLFE.

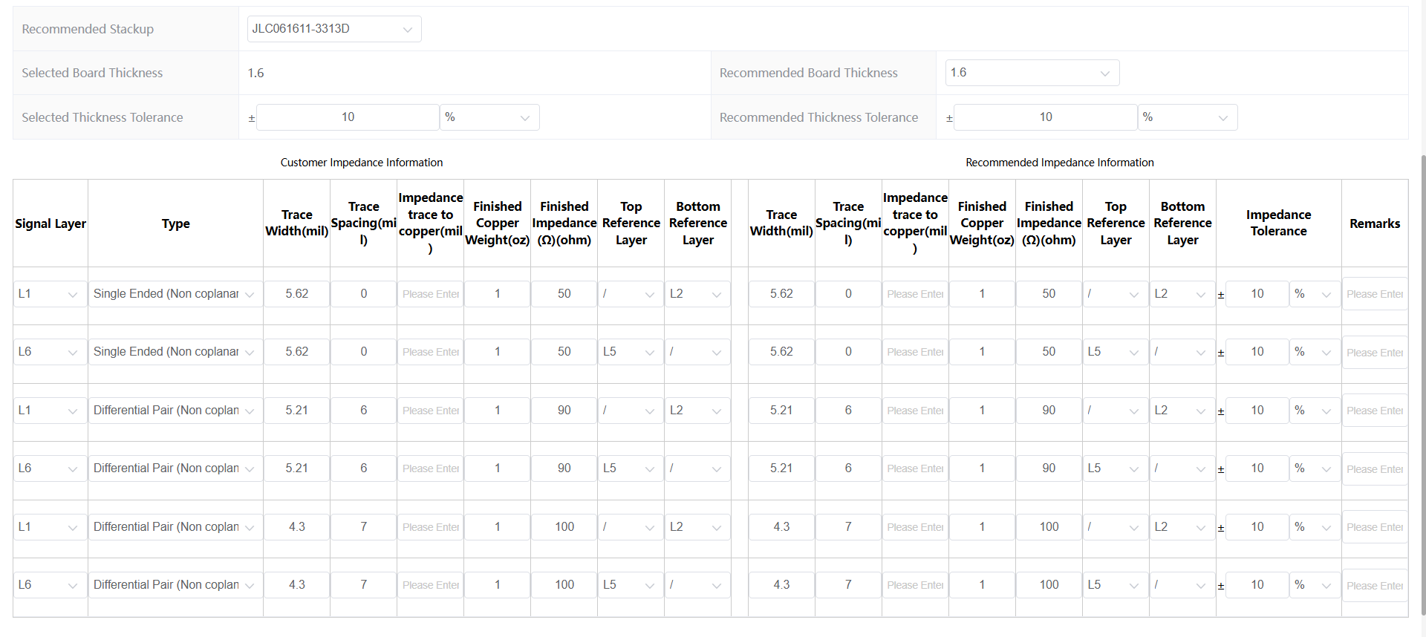
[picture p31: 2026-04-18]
Production/PCB Rev 1/JLCPCB_Rev1_Build/Impedance Calculations/fromJLC_ImpCalc.png

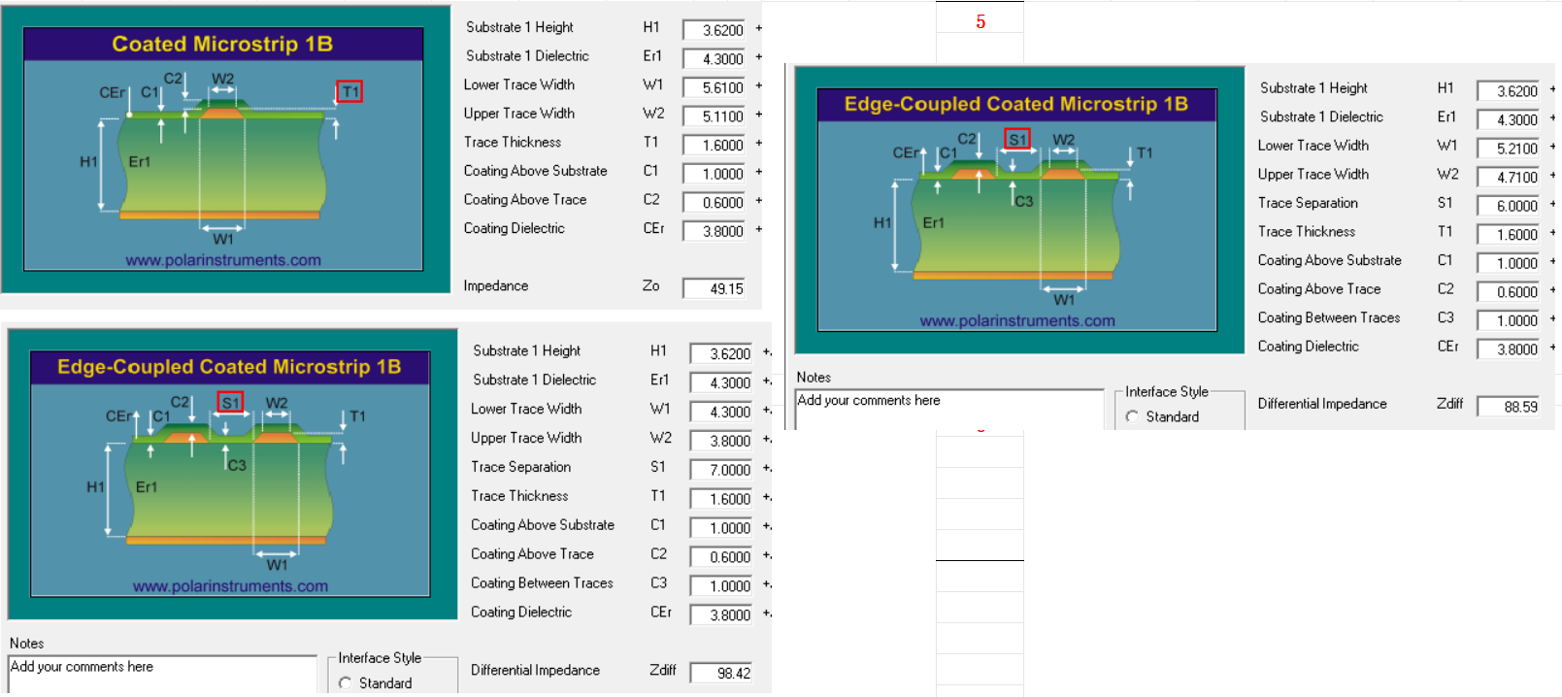
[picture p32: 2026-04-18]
Production/PCB Rev 1/JLCPCB_Rev1_Build/Impedance Calculations/fromJLC_Si9000e.png

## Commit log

2026-04-11 Initial commit of iMX6 Bare Bones PCBA project. Schematic: Rev 2, PCB: Rev 1.
    [141_800SP9B10M6xE.stp, 218-2.STEP, 218-4.STEP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]
2026-04-18 Minor changes to Layers 3 and 4.
    [iMX6_BareBones-B_Cu.gbl, iMX6_BareBones-B_Fab.gbr, iMX6_BareBones-B_Mask.gbs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]
2026-04-18 Updated PCBA top image.
2026-04-23 For JLC DFM, added ground pours to L1 and L6. Updated soldermask expansion on U2 footprint.
    [Block_Diagram.kicad_sch, BootMode.kicad_sch, CAN.kicad_sch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]
2026-04-23 Added JLC production gerbers and impedance calculations.
    [iMX6_BareBones-B_Cu.gbl, iMX6_BareBones-B_Fab.gbr, iMX6_BareBones-B_Mask.gbs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]

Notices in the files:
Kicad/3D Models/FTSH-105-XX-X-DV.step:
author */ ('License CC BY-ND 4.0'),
